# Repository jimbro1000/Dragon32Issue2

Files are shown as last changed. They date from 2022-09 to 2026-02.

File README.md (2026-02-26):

# DRAGON 32 CPU Issue 2 #

This project is a recreation of the SA2120 CPU Mainboard 
for the 1982 Dragon Data **Dragon 32**

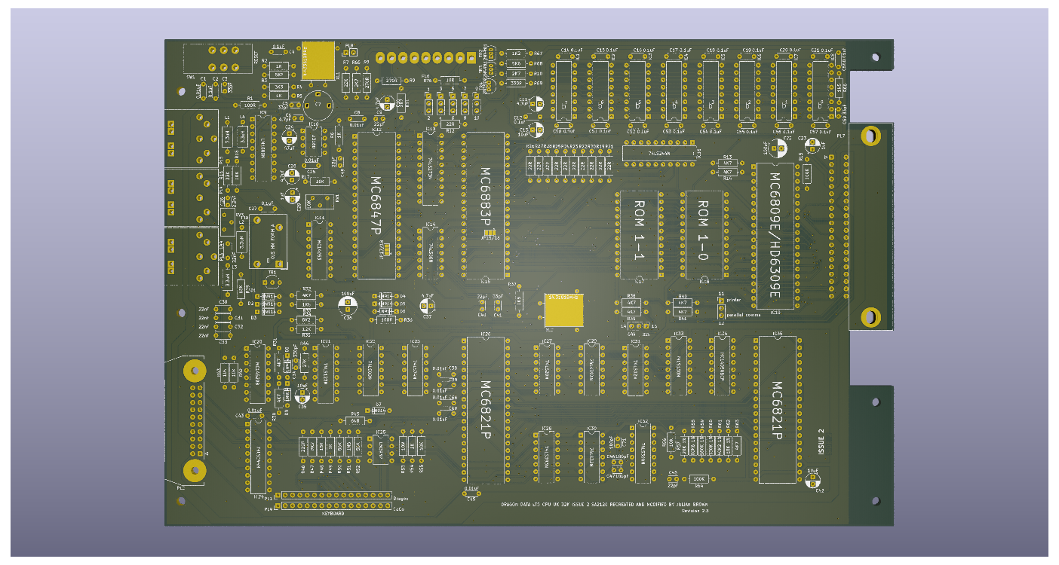
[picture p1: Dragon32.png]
Render of reproduction board


Everything (excluding modifications) is taken from the SA2120
schematics. Component positioning is as close to the original
too. The DRAM positions are as close as possible to the 1982
board but in preference use 4164s instead and set the
memory configuration jumpers appropriately, this avoids 
transplanting a riser board to use the 16x16k configuration.
The 16x16k should still work of course...

The two ROMS will need to be sourced from original boards or an
adapter used to allow the use of modern, available EPROM or EEPROM
components

The variable resistor (RV1) and motor relay (RL1) are adjusted 
for modern, available components. The cartridge port is based
on a modern design but may still be hard to source

## Important - Read This Bit! ##

September 2023: **In the year since I started developing this board the 
availability of the MC6883P/74LS783N SAM chip has gone from "easy to 
find" to almost unobtainable. The only known and proven source is from
DragonPlus Electronics. Please make sure you can find one before starting 
your build**

There is work being done to create a replacement for the SAM chip
but this is yet to become available

The rarer (but ironically easier to buy) 74LS785 should work as
a substitute

## Caveat ##

The scans on the original SA2120 schematics are not always clear
and it has taken a fair amount of careful study to get everything
correct but there is no guarantee at this time that the board 
design is as intended

The values of passive components are taken from observation of
an original production board, in most cases those values do
match the schematics, but not always

Revision 2.3 of this board is in a genuinely usable state but
still with caveats

### Working ###

In the current state (2.3) basic operation is tested working on
CPU, RAM, Keyboard, Joystick and Video.

### Working with caveat ###

Audio appears to be good but not fully tested (given the joysticks
work and the board produces audio there isn't much to go wrong
here)

### Untested ###

Parallel port is untested in either mode beyond verifying signals
to the port are present

## Modifications ##
### Joysticks ###

The two joystick ports provide a second fire button capability
wired to consecutive keyboard rows, as per the Tandy CoCo. 
Unless a two button joystick is used this make no difference to
the operation of the computer. It also requires the use of 6-pin 
DIN sockets, these are pin compatible with the 5-pin originals
so a regular single button joystick can still be used.

The two extra buttons can also be disabled by omitting L3 and L4

### Parallel Port ###

An extra jumper has been introduced to bypass the logic inverter
on the STROBE line. When bypassed the parallel port should 
operate as a communication port for DRIVEWIRE. In effect this
enables the printer port to behave as a TTL serial connection. 
Speed is limited by software and raw clock speed.

### Memory Addressing ###

The board is configurable between 32k and 64k ram addressing
using jumper 13/14. Position 13 is for original 32k ram
configuration, position 14 is for an upgraded 64k ram. Note
that this then requires removal of some additional passive 
components and assumes that suitable 64k x 1 ram chips are 
fitted in IC1 to IC8.

Jumper 9/10 has been added for consistency with some of the
other early designs and for compatibility with the 64k
upgrade. It is important to avoid populating C50-57 when
using this option, along with C12, C58, C59 and R66.

See [World of Dragon: Dragon 32 - 64k Upgrade]
(http://archive.worldofdragon.org/index.php?title=Dragon_32_-_64K_Upgrade)

## Video ##

The Rev 2.1 board adds two (hidden) solder jumpers for adapting
the board to NTSC output. By default these have a bridge putting
the board in PAL mode so unless you want NTSC output there is
nothing to be done.

To change the configuration the bridge on both jumpers needs to be
cut and the option pads bridged with solder. This bypasses the
additional logic for video sync. The jumpers are JP15/16 and 
JP17/18, these are positioned below IC15 and IC12 respectively. 
The default position is marked.

To complete the change an NTSC adapter board needs to be fitted.
This piggybacks the 6847 position and adds in a suitable NTSC
video modulator. The output of the NTSC board goes to PL8, next
to the PAL colour crystal XL1.

In this configuration there is no need to fit a number of components:

* IC9
* IC10
* IC11
* IC14
* IC21
* IC22
* IC26
* IC27
* IC29
* IC30
* IC32
* C2
* C3
* C5
* C6
* C7
* C24
* C25
* C28
* C46
* C47
* C71
* R2
* R3
* R4
* R17
* R18
* R33
* R34
* R35
* R44
* XL1

## Substitutions ##

Many of the original components are simply unobtainable or
just very hard (and expensive) to locate. The transistors
will need modern substitutes as the BC141, BC212 and 2N2369
are all obsolete but thankfully these are fairly run-of-the-mill
transistors and shouldn't cause any particular issues

The video op-amp SFC2318D at position IC10 is especially
hard to find and this one component can easily double the
price of populating the board if an original is used...
I've identified a Harris HA-5111 as a likely candidate, it
is an audio op-amp rated for upto 40MHz so plenty of 
bandwitdh for a simple PAL/NTSC video signal. There are of 
course lots of other single channel op-amps out there in a 
dip-8 format but they tend to be expensive (as in *really*
expensive) possibly cheaper than a real 2318D but not by
much, some are stupidly expensive (nearly 100x that
2318D). The HA-5111 should be about £0.90

The CPU, PIAs and VDG are all fairly easy to obtain online
and possibly even new (MC6821s are still made and there
are lots of compatible alternatives). A and B rated components
should all be usable but make sure the processor is an "09e".
The Hitachi HD6309 is usable but may cause crashes in some
software due to lazy coding

The 4000 series logic chips are particularly tricky - some
have modern equivalents. The MC14053 and MC14050 can be
replaced with modern CD4000 series chips. The MC14529
was replaced with a CD4000 series logic chip but even that
is now obsolete with no valid replacement

The LM1889 is another hard to find chip but still reasonably
cheap online when found

The SAM and the two ROMs are genuinely unavailable except 
from donor boards but the ROMs can be replaced with 27C64
eproms fitted with a suitable conversion shim board.

### The Future ###

As these parts become harder to find it is inevitable that
replacements and redesigns will be needed. Abandoning the
original composite video output circuits and moving to a
(more) modern RGB or VGA output instead removes a big
chunk of the more troublesome hardware, notably the LM1889
and SFC2318 along with a number of other common logic chips.
If a composite output is still required an ADR724J can be
used to generate the necessary signal, all in one chip

A cheat replacement for the 6847 exists, using a raspberry
pi pico but this could easily be reduced even further an
FPGA (assuming such chips are readily available again)

The ROMs can be replaced with a single EPROM/EEPROM, even
opening up the option of switchable ROM images given the
size of a modern EPROM's addressable memory. I have a
mini conversion board that fits into a single socket with
a jumper to the E pin of the second socket. (see 
https://github.com/jimbro1000/Dragon32RomFix)

The one thing that isn't so quickly removed from the
equation is that MC14529 - a dual 4-channel data
selector. Onsemi and Harris used to made the CD4529
that replaced the original MC14529 and it is only fairly 
recently that the chip became obsolete so there is
stock out there but the chip is somewhat specialised and
as such really isnt easily substituted even with a modern
SMD package.

The most likely candidate here is to use a GAL chip to 
simulate the switching behaviour of the MC14529 combined
with discrete analogue switches (such as 74LVC1G3157). This
will necessitate a new board design or a plugin board to
match the pinout of the 4529 chip

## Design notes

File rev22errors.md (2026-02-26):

* jumper 11/12 incorrectly wired to separate direct and inverted signals to STROBE *

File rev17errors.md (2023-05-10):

# Errors found on Rev 1.7 board #

* C7 footprint incorrect - through-hole pads too small for component
* RV3 footprint clashing with PL4 and PL5 - moved to provide additional clearance
* Chrome output from IC9 corrected
* Pins 2 and 3 of IC 10 reversed
* C24 low at 4.7uF, increased to 47uF
* R34 high at 8K8, reduced to 8K2ohms
* R33 low at 1K2, increased to 1K8ohms

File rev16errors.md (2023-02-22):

__Due to a rebase merge conflict earlier corrections have been lost__

* +5V and -5V connections to board are reversed

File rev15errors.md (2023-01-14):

* missing lumcontrol trace added
* correct carry trace between block A and B of IC32
* correct +v to IC25
* correct PIA2/IC35 output to DAC ladder
* revise values for R33, R34 and R35

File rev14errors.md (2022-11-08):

* RL1 footprint reversed
* PL7 mounting holes redesigned to suit original and modern connectors
* PL6 +/-5v power lines reversed

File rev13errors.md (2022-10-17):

* footprint PL7 - updated
* C10 incorrectly wired in schematic - changed to polarized and rewired, only affects 16k layout
* C11 - changed to polarized and rewired
* C13 - changed to polarized and rewired
* C24 - changed to polarized and rewired
* C28 - changed to polarized and rewired
* C37 - changed to polarized and rewired
* C43 - moved to more efficient position
* footprint RL1 - updated
* footprint RV1 - updated
* IC35 - IC20 restored missing connection CB2 <-> STy
* Fix mixup of Q and E on 6883 (IC15)
* R4 pad 2 routed to -5V instead of GND
* IC25 - IC26 restored missing connection to PA7
* IC10 -V connected to -5V instead of GND

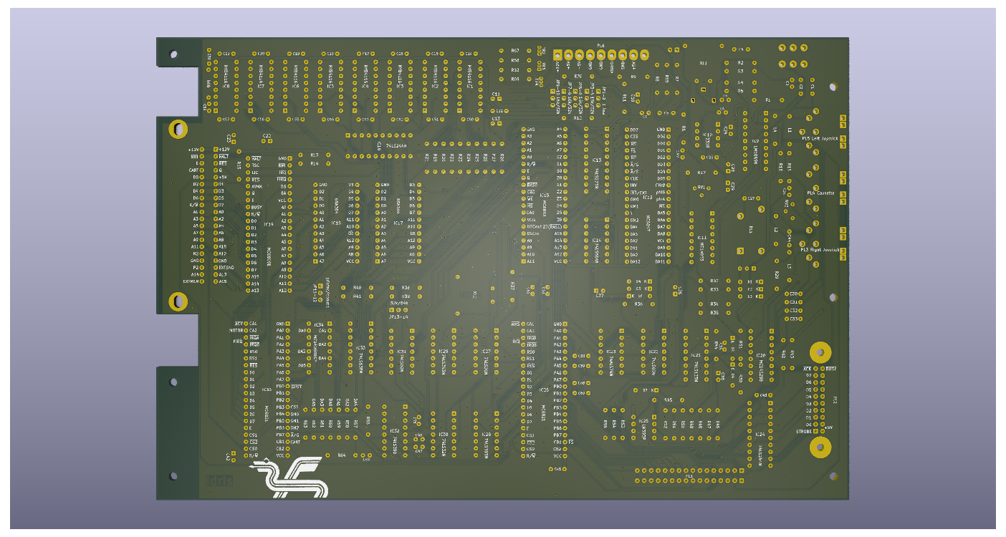
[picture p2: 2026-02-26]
Dragon32c.png

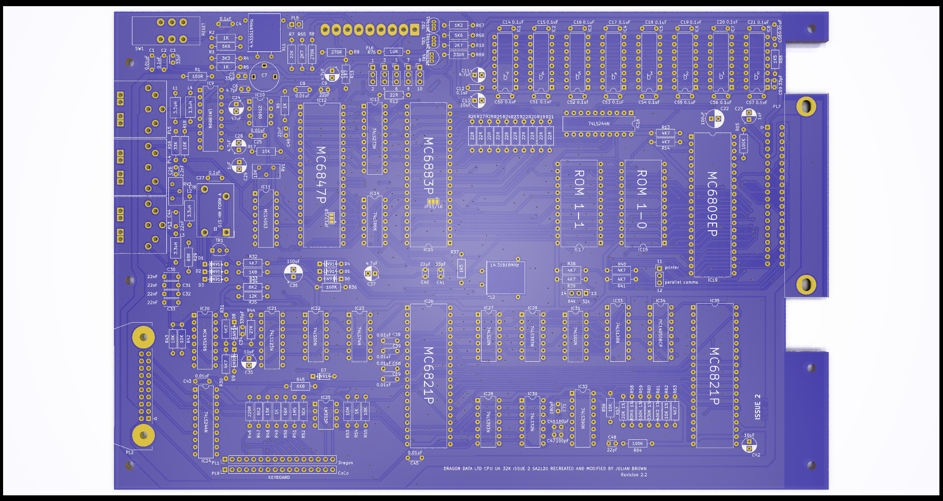
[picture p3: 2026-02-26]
Dragon32b.png

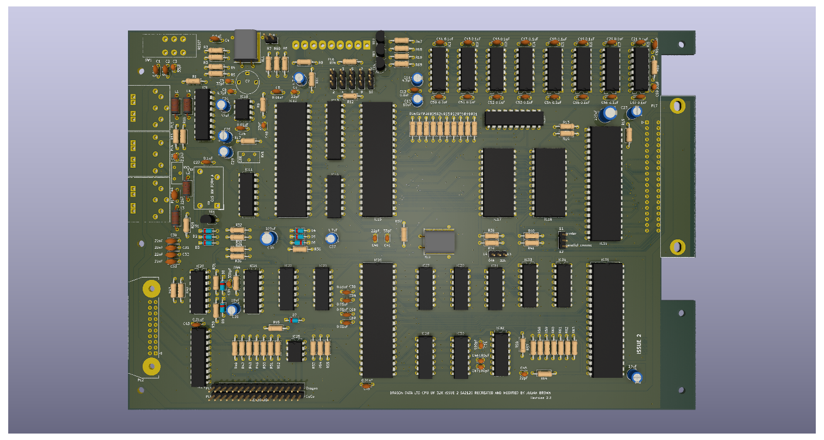
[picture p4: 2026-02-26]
Dragon32a.png

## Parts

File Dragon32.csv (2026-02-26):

Reference | Value | Datasheet | Footprint | Qty | DNP | DigiKey | Mouser
C1,C8,C25,C38,C39,C43,C45,C58,C68,C69 | 0.01uF | https://www.vishay.com/docs/45171/kseries.pdf | Capacitor_THT:C_Disc_D4.3mm_W1.9mm_P5.00mm | 10 |  | BC2662CT-ND
C2,C4,C12,C14,C15,C16,C17,C18,C19,C20,C21,C27,C50,C51,C52,C53,C54,C55,C56,C57 | 0.1uF | https://www.vishay.com/docs/45171/kseries.pdf | Capacitor_THT:C_Disc_D4.3mm_W1.9mm_P5.00mm | 20 |  | BC1101CT-ND
C3,C5,C41,C59 | 33pF | https://www.vishay.com/docs/45171/kseries.pdf | Capacitor_THT:C_Disc_D3.0mm_W2.0mm_P2.50mm | 4 |  | BC1007CT-ND
C6 | 4.7pF |  | Capacitor_THT:C_Disc_D3.0mm_W2.0mm_P2.50mm | 1 |  | 445-180473-1-ND
C7 | 2-22pF | https://connect.kemet.com:7667/gateway/IntelliData-ComponentDocumentation/1.0/download/datasheet/C315C220K2G5TA7301 | Dragon:Trimmer-7.5mm | 1 |  | 4363-PPXE27000-ND
C9,C40,C48,C49 | 22pF | https://connect.kemet.com:7667/gateway/IntelliData-ComponentDocumentation/1.0/download/datasheet/C315C220K2G5TA7301 | Capacitor_THT:C_Disc_D3.0mm_W2.0mm_P2.50mm | 4 |  | 399-13930-1-ND
C10,C11,C28,C37 | 4.7uF | https://datasheets.kyocera-avx.com/tap.pdf | Capacitor_THT:CP_Radial_D5.0mm_P2.50mm | 4 |  | 478-8984-1-ND
C13,C35,C42 | 10uF | https://www.we-online.com/katalog/datasheet/860010372001.pdf | Capacitor_THT:CP_Radial_D5.0mm_P2.50mm | 3 |  | 732-8593-1-ND
C22,C36 | 100uF | https://www.we-online.com/katalog/datasheet/860010372006.pdf | Capacitor_THT:CP_Radial_D6.3mm_P2.50mm | 2 |  | 732-8598-1-ND
C23,C29 | 1uF | https://www.we-online.com/katalog/datasheet/860020772005.pdf | Capacitor_THT:CP_Radial_D5.0mm_P2.50mm | 2 |  | 732-8966-1-ND
C24 | 47uF | https://datasheets.kyocera-avx.com/tap.pdf | Capacitor_THT:CP_Radial_D5.0mm_P2.50mm | 1 |  | 478-8984-1-ND
C26 | 2.2nF | https://www.vishay.com/docs/45171/kseries.pdf | Capacitor_THT:C_Disc_D3.0mm_W2.0mm_P2.50mm | 1 |  | BC1074CT-ND
C30,C31,C32,C33,C44 | 22nF | https://www.vishay.com/docs/45171/kseries.pdf | Capacitor_THT:C_Disc_D5.0mm_W2.5mm_P5.00mm | 5 |  | BC2677CT-ND
C34 | 330pF | https://www.vishay.com/docs/45171/kseries.pdf | Capacitor_THT:C_Disc_D3.0mm_W2.0mm_P2.50mm | 1 |  | BC1045CT-ND
C46,C71 | 180pF | https://www.vishay.com/docs/45171/kseries.pdf | Capacitor_THT:C_Disc_D3.0mm_W2.0mm_P2.50mm | 2 |  | BC1016CT-ND
C47 | 100pF | https://connect.kemet.com:7667/gateway/IntelliData-ComponentDocumentation/1.0/download/datasheet/C316C101J5G5TA7303 | Capacitor_THT:C_Disc_D3.0mm_W2.0mm_P2.50mm | 1 |  | 399-C316C101J5G5TA7303CT-ND
D1,D2,D3,D4,D5,D6,D7,D8,D9 | 1N914 | http://www.vishay.com/docs/85622/1n914.pdf | Diode_THT:D_DO-35_SOD27_P7.62mm_Horizontal | 9 |  | 1N914FS-ND
IC1,IC2,IC3,IC4,IC5,IC6,IC7,IC8 | HYB4116 | https://4donline.ihs.com/images/VipMasterIC/IC/INFN/INFNS18263/INFNS18263-1.pdf | Package_DIP:DIP-16_W7.62mm | 8 |  |  | 517-4816-3000-CP
IC9 | LM1889N | https://www.alldatasheet.com/datasheet-pdf/pdf/8687/NSC/LM1889N.html | Package_DIP:DIP-18_W7.62mm | 1 |  |  | 517-4818-3000-CP
IC10 | 2318 | https://ww1.microchip.com/downloads/en/DeviceDoc/20001811F.pdf | Package_DIP:DIP-8_W7.62mm | 1 |  | MCP6281-E/P-ND
IC11 | MC14053 | https://rocelec.widen.net/view/pdf/kdbfj5guvk/MOTOS09506-1.pdf?t.download=true&u=5oefqw | Package_DIP:DIP-16_W7.62mm | 1 |  | 296-2059-ND
IC12 | MC6847 |  | Package_DIP:DIP-40_W15.24mm | 1 |  |  | 517-4840-6000-CP
IC13 | 74LS273N | http://www.ti.com/lit/gpn/sn74LS273 | Package_DIP:DIP-20_W7.62mm | 1 |  | 296-1657-5-ND
IC14 | 74LS86AN | https://media.digikey.com/pdf/Data%20Sheets/Fairchild%20PDFs/DM74LS86.pdf | Package_DIP:DIP-14_W7.62mm | 1 |  | 296-1669-5-ND
IC15 | MC6883 | http://www.colorcomputerarchive.com/coco/Documents/Datasheets/MC6883 Synchronous Address Multiplexer (Motorola).pdf | Package_DIP:DIP-40_W15.24mm | 1 |  |  | 517-4840-6000-CP
IC16,IC24 | 74LS244N | http://www.ti.com/lit/ds/symlink/sn74ls244.pdf | Package_DIP:DIP-20_W7.62mm | 2 |  | 296-1653-5-ND
IC17,IC18 | 68A364 |  | Package_DIP:DIP-24_W15.24mm | 2 |  |  | 517-4824-6000-CP
IC19 | MC6809E | http://pdf.datasheetcatalog.com/datasheet/motorola/MC68B09S.pdf | Package_DIP:DIP-40_W15.24mm | 1 |  |  | 517-4840-6000-CP
IC20 | MC14529B |  | Package_DIP:DIP-16_W7.62mm | 1 |  | CD4529BCN-ND
IC21 | 74LS123N | http://www.ti.com/lit/gpn/sn74LS123 | Package_DIP:DIP-16_W7.62mm | 1 |  | 296-1636-5-ND
IC22 | 74LS00N | http://www.ti.com/lit/gpn/sn74ls00 | Package_DIP:DIP-14_W7.62mm | 1 |  | 296-1626-ND
IC23 | 74ALS74N | https://www.ti.com/lit/ds/symlink/sn74als74a.pdf | Package_DIP:DIP-14_W7.62mm | 1 |  | 296-1506-5-ND
IC25 | LM393P | http://www.ti.com/lit/ds/symlink/lm393.pdf | Package_DIP:DIP-8_W7.62mm | 1 |  | 296-1398-5-ND
IC26,IC35 | MC6821 |  | Package_DIP:DIP-40_W15.24mm | 2 |  |  | 517-4840-6000-CP
IC27 | 74LS20N | http://www.ti.com/lit/gpn/sn74LS20 | Package_DIP:DIP-14_W7.62mm | 1 |  | 296-3670-5-ND
IC28,IC29 | 74LS393N | https://www.ti.com/general/docs/suppproductinfo.tsp?distId=10 | Package_DIP:DIP-14_W7.62mm | 2 |  | 296-1665-5-ND
IC30 | 74LS32N | http://www.ti.com/lit/gpn/sn74LS32 | Package_DIP:DIP-14_W7.62mm | 1 |  | 296-1658-5-ND
IC31 | 74LS02N | http://www.ti.com/lit/gpn/sn74ls02 | Package_DIP:DIP-14_W7.62mm | 1 |  | 296-1627-5-ND
IC32 | 74LS390 | http://www.ti.com/lit/gpn/sn74LS390 | Package_DIP:DIP-16_W7.62mm | 1 |  | 296-26516-5-ND
IC33 | 74LS138N | http://www.ti.com/lit/gpn/sn74LS138 | Package_DIP:DIP-16_W7.62mm | 1 |  | 296-1639-5-ND
IC34 | MC14050BCP | https://media.digikey.com/pdf/Data%20Sheets/ON%20Semiconductor%20PDFs/MC14049B,50B_Rev7.pdf | Package_DIP:DIP-16_W7.62mm | 1 |  | 296-2056-ND
JP1-2 | 1 low | ~ | Connector_PinHeader_2.54mm:PinHeader_1x03_P2.54mm_Vertical | 1 |  |  | 538-22-28-5033
JP3-4,JP5-6,JP7-8,JP9-10 | 16k/32k | ~ | Connector_PinHeader_2.54mm:PinHeader_1x03_P2.54mm_Vertical | 4 |  |  | 538-22-28-5033
JP11-12 | printer/comms | ~ | Connector_PinHeader_2.54mm:PinHeader_1x03_P2.54mm_Vertical | 1 |  |  | 538-22-28-5033
JP13-14 | 32k/64k | ~ | Connector_PinHeader_2.54mm:PinHeader_1x03_P2.54mm_Vertical | 1 |  |  | 538-22-28-5033
L1,L2,L3,L4 | 3.3uH | ~ | Inductor_THT:L_Axial_L7.0mm_D3.3mm_P10.16mm_Horizontal_Fastron_MICC | 4 |  | 495-5561-1-ND
PL1 | Dragon Keyboard | ~ | Connector_PinHeader_2.54mm:PinHeader_1x16_P2.54mm_Vertical | 1 |  | 952-2521-ND
PL2 | Printer | https://media.digikey.com/pdf/Data%20Sheets/CW%20Industries%20PDFs/CWN-300%20Ordering.pdf | Connector_IDC:IDC-Header_2x10-1MP_P2.54mm_Latch_Horizontal | 1 |  | CHR20G-ND
PL3 | DIN-6 J/S R | https://www.dem-uk.com/deltron-components/Data/Product_Downloads/deltron-671-0501-5-way-din-socket-data.pdf | Dragon:DIN-6_DELTRON_671-0601_Horizontal | 1 |  | CP-7060-ND
PL4 | DIN-5 (180) Cassette | https://www.dem-uk.com/deltron-components/Data/Product_Downloads/deltron-671-0501-5-way-din-socket-data.pdf | Dragon:DIN-5_DELTRON_671-0501_45deg_Horizontal | 1 |  | CP-7050-ND
PL5 | DIN-6 J/S L | https://www.dem-uk.com/deltron-components/Data/Product_Downloads/deltron-671-0501-5-way-din-socket-data.pdf | Dragon:DIN-6_DELTRON_671-0601_Horizontal | 1 |  | CP-7060-ND
PL6 | Power Board Interconnect | https://app.adam-tech.com/products/download/data_sheet/241222/lhd-xx-ts-data-sheet.pdf | Connector_Molex:Molex_KK-396_A-41791-0009_1x09_P3.96mm_Vertical | 1 |  | 2057-LHD-09-TS-ND
PL7 | EDAC 392-040-558-201 | https://files.edac.net/edac/content/342/342-040-558-212%20-%20EDAC%20Card%20Edge%20Connector.PDF | Dragon:Edge_2x20_P2.54mm_OvalMP | 1 |  | 151-342-040-558-201-ND | 587-342-040-558-201
PL8 | video | ~ | Connector_PinHeader_2.54mm:PinHeader_1x02_P2.54mm_Vertical | 1 |  |  | 538-22-28-4024
PL9 | CoCo Keyboard | ~ | Connector_PinHeader_2.54mm:PinHeader_1x16_P2.54mm_Vertical | 1 |  |  | 538-22-28-8161
R1 | 100R | ~ | Resistor_THT:R_Axial_DIN0207_L6.3mm_D2.5mm_P10.16mm_Horizontal | 1 |  | CF14JT100RCT-ND
R2,R5,R6,R49,R54 | 1K | ~ | Resistor_THT:R_Axial_DIN0207_L6.3mm_D2.5mm_P10.16mm_Horizontal | 5 |  | CF14JT1K00CT-ND
R3,R68 | 5K6 | ~ | Resistor_THT:R_Axial_DIN0207_L6.3mm_D2.5mm_P10.16mm_Horizontal | 2 |  | CF14JT5K60CT-ND
R4 | 3K3 | ~ | Resistor_THT:R_Axial_DIN0207_L6.3mm_D2.5mm_P10.16mm_Horizontal | 1 |  | CF14JT3K30CT-ND
R7 | 22K | ~ | Resistor_THT:R_Axial_DIN0207_L6.3mm_D2.5mm_P10.16mm_Horizontal | 1 |  | CF14JT22K0CT-ND
R8,R9 | 270R | ~ | Resistor_THT:R_Axial_DIN0207_L6.3mm_D2.5mm_P10.16mm_Horizontal | 2 |  | CF14JT270RCT-ND
R10,R11,R65 | 2K7 | ~ | Resistor_THT:R_Axial_DIN0207_L6.3mm_D2.5mm_P10.16mm_Horizontal | 3 |  | CF14JT2K70CT-ND
R12,R19,R20,R21,R22,R23,R24,R25,R26,R27,R28 | 22R | ~ | Resistor_THT:R_Axial_DIN0207_L6.3mm_D2.5mm_P10.16mm_Horizontal | 11 |  | CF14JT22R0CT-ND
R13,R14,R30,R31,R32,R38,R39,R40,R41,R63 | 4K7 | ~ | Resistor_THT:R_Axial_DIN0207_L6.3mm_D2.5mm_P10.16mm_Horizontal | 10 |  | CF14JT4K70CT-ND
R15,R36,R64 | 100K | ~ | Resistor_THT:R_Axial_DIN0207_L6.3mm_D2.5mm_P10.16mm_Horizontal | 3 |  | CF14JT100KCT-ND
R16 | 33K | ~ | Resistor_THT:R_Axial_DIN0207_L6.3mm_D2.5mm_P10.16mm_Horizontal | 1 |  | CF14JT33K0CT-ND
R17,R18,R42,R43,R55,R56 | 10K | ~ | Resistor_THT:R_Axial_DIN0207_L6.3mm_D2.5mm_P10.16mm_Horizontal | 6 |  | CF14JT10K0CT-ND
R29 | 68K | ~ | Resistor_THT:R_Axial_DIN0207_L6.3mm_D2.5mm_P10.16mm_Horizontal | 1 |  | CF14JT68K0CT-ND
R33 | 1K8 | ~ | Resistor_THT:R_Axial_DIN0207_L6.3mm_D2.5mm_P10.16mm_Horizontal | 1 |  | CF14JT3K30CT-ND
R34,R47 | 8K2 | ~ | Resistor_THT:R_Axial_DIN0207_L6.3mm_D2.5mm_P10.16mm_Horizontal | 2 |  | CF14JT8K20CT-ND
R35 | 12K | ~ | Resistor_THT:R_Axial_DIN0207_L6.3mm_D2.5mm_P10.16mm_Horizontal | 1 |  | CF14JT15K0CT-ND
R37,R66 | 1K5 | ~ | Resistor_THT:R_Axial_DIN0207_L6.3mm_D2.5mm_P10.16mm_Horizontal | 2 |  | CF14JT1K50CT-ND
R44 | 27K | ~ | Resistor_THT:R_Axial_DIN0207_L6.3mm_D2.5mm_P10.16mm_Horizontal | 1 |  | CF14JT27K0CT-ND
R45 | 6K8 | ~ | Resistor_THT:R_Axial_DIN0207_L6.3mm_D2.5mm_P10.16mm_Horizontal | 1 |  | CF14JT6K80CT-ND
R46 | 220R | ~ | Resistor_THT:R_Axial_DIN0207_L6.3mm_D2.5mm_P10.16mm_Horizontal | 1 |  | CF14JT220RCT-ND
R48 | 15K | ~ | Resistor_THT:R_Axial_DIN0207_L6.3mm_D2.5mm_P10.16mm_Horizontal | 1 |  | CF14JT15K0CT-ND
R50,R52 | 56K | ~ | Resistor_THT:R_Axial_DIN0207_L6.3mm_D2.5mm_P10.16mm_Horizontal | 2 |  | CF14JT56K0CT-ND
R51 | 1M5 | ~ | Resistor_THT:R_Axial_DIN0207_L6.3mm_D2.5mm_P10.16mm_Horizontal | 1 |  | CF14JT1M50CT-ND
R53 | 10M | ~ | Resistor_THT:R_Axial_DIN0207_L6.3mm_D2.5mm_P10.16mm_Horizontal | 1 |  | CF14JT10M0CT-ND
R57 | 20K 1% | ~ | Resistor_THT:R_Axial_DIN0207_L6.3mm_D2.5mm_P10.16mm_Horizontal | 1 |  | RNF14FTD20K0CT-ND
R58 | 80K6 1% | ~ | Resistor_THT:R_Axial_DIN0207_L6.3mm_D2.5mm_P10.16mm_Horizontal | 1 |  | RNF14FTD80K6CT-ND
R59 | 160K 1% | ~ | Resistor_THT:R_Axial_DIN0207_L6.3mm_D2.5mm_P10.16mm_Horizontal | 1 |  | S160CACT-ND
R60 | 330K 1% | ~ | Resistor_THT:R_Axial_DIN0207_L6.3mm_D2.5mm_P10.16mm_Horizontal | 1 |  | S330KCACT-ND
R61 | 40K2 1% | ~ | Resistor_THT:R_Axial_DIN0207_L6.3mm_D2.5mm_P10.16mm_Horizontal | 1 |  | RNF14FTD41K2CT-ND
R62 | 10K 1% | ~ | Resistor_THT:R_Axial_DIN0207_L6.3mm_D2.5mm_P10.16mm_Horizontal | 1 |  | RNF14FTD10K0CT-ND
R67 | 1K2 | ~ | Resistor_THT:R_Axial_DIN0207_L6.3mm_D2.5mm_P10.16mm_Horizontal | 1 |  | CF14JT1K20CT-ND
R69 | 330R | ~ | Resistor_THT:R_Axial_DIN0207_L6.3mm_D2.5mm_P10.16mm_Horizontal | 1 |  | CF14JT330RCT-ND
R76 | 10R | ~ | Resistor_THT:R_Axial_DIN0207_L6.3mm_D2.5mm_P10.16mm_Horizontal | 1 |  | CF14JT10R0CT-ND
RL1 | OJS HM FORM A | https://www.te.com/commerce/DocumentDelivery/DDEController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 | Dragon:OJS HM 10A Relay | 1 |  | 41-OJS-SH-105HMF,00000-ND
RV1 | 10K | ~ | Potentiometer_THT:Potentiometer_Bourns_3386X_Horizontal | 1 |  | 3386C-103LF-ND
RV3 | 470R | ~ | Potentiometer_THT:Potentiometer_Bourns_3386X_Horizontal | 1 |  | 3386H-103LF-ND
SW1 | RESET | https://www.ckswitches.com/media/1402/fpush.pdf | Dragon:Button_AlpsAlpine_SPUN190900 | 1 |  | 401-1225-ND
TR1 | BC141 | https://alltransistors.com/adv/pdfview.php?doc=bc140_bc141_cnv_2.pdf&dire=_philips | Package_TO_SOT_THT:TO-92_Inline_Wide | 1 |  | SS8050DTACT-ND
TR2,TR3 | 2N4401 | http://www.farnell.com/datasheets/296634.pdf | Package_TO_SOT_THT:TO-92_Inline | 2 |  | 2N4401D26ZCT-ND
TR4 | 2N3906 | https://www.onsemi.com/pub/Collateral/2N3906-D.PDF | Package_TO_SOT_THT:TO-92_Inline | 1 |  | 2N3906D26ZCT-ND
XL1 | 4.433619MHz | https://www.we-online.com/catalog/datasheet/830003099B.pdf | Crystal:Crystal_HC49-U_Horizontal | 1 |  | 1923-830003099B-ND
XL2 | 14.31818MHz | https://www.ctscorp.com/wp-content/uploads/MP.pdf | Crystal:Crystal_HC49-U_Horizontal | 1 |  | CTX088-ND

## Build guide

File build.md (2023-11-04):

# Dragon 32 Rev 2 Build Instructions #

## Introduction ##

This is a rough guide on how to assemble the 
Dragon 32 Rev 2 reproduction board. It assumes 
you have collected together all the parts you 
will need using the bill of materials in the 
project repository.

## Preparation ##

Clean the mainboard to remove contaminants, soapy
water first, dry and then a wipe down with 
isopropy alcohol.

Make sure you have a good supply of solder, a
temperature controlled soldering iron. If you
are using lead based solder set the temperature
to between 360C and 370C. The board can tolerate
higher for lead-free solder.

A ready supply of solder flux can be really
helpful if you find yourself having to remove a
component from the board.

You will need short tipped, angled wire cutters
for trimming the component leads after soldering.
Don't cut the leads right down to the board or deep
into the solder.

It is also a good idea to have a multimeter on hand
to check component values and test for any shorts
after soldering.

The project repository on GitHub includes an
interactive Bill Of Materials that allows you to
cross-reference components against position on
the board (and mark off all the parts that you've
fitted). To use this download the ibom.html file
to your computer and open it from the local file
system (this should open up a web browser).

If you can't or don't want to use the iBOM it is
a good idea to print off the Dragon32__Assembly 
PDF on to large form paper and mark the positions 
off from there as they are fitted to help avoid
getting lost.

## Build Order ##

Work with the components with the lowest profile
first - resistors, then diodes, then capacitors,
transistors, etc.

Leaving the chip sockets until last helps as they 
tend to get in the way when fitting other items.

### PAL/NTSC configuration ###

If you are setting the board up to use NTSC you
need to start by modifying JP15/16 and JP17/18.
By default these are pre-bridged for PAL use.
You need to cut the trace joining pads 1 and 2
on both jumpers. Pad 1 is marked with a triangle.

Once the trace is cut, use a blob of solder to
join pads 2 and 3.

To use NTSC you need to provide an adapter to the
VDG that includes an MC1372 NTSC modulator chip.
This replaces most of the discrete logic on the
board.

The output of the adapter board is wired to PL8.
Ground on the left, composite NTSC video on the
right.

The rest of this build assumes you are assembling
for a PAL machine.

### Resistors ###

Fit resistors first making sure the solder is
forming on both sides of the board, not just
the bottom.

Regardless of board configuration all of the
resistors should be fitted.

Save the two potentiometer resistors RV1 and RV2
for later.

### Diodes ###

Fit all 9 diodes in much the same way as the
resistors but making sure the polarity marking
matches the board.

### Inductors ###

If you want to have the option of two button
joysticks (non-standard but used in some
CoCo games) then you'll need to fit all 4
inductors (L1-L4).

If you only want single button joysticks you
only need to fit L1 and L2.

Soldering is the same as for resistors.

### Capacitors ###

If you are using 4164 DRAM chips you need to
miss some components out. C12 and C50-C57
must not be fitted - failing to do this will
result in corrupted memory read and write.

Other than this fit all capacitors making 
sure that the tantalum and electrolytic
capacitors are fitted the right way around.

Tantalum capacitors have a + symbol next to
the positive side. Electrolytic capacitors
have an arrow pointing to the negative side.

The board is marked to show a + next to the
positive side and a filled semicircle on the
negative side.

It is worth saving two of the long legs
after trimming the legs back. You can use
these for securing the crystals.

Save the trim pot capacitor C7 for later.

### Transistors ###

TR1 is an NPN transistor driving the coil of
the cassette remote relay. It uses a wide
TO-92 footprint.

TR2 and TR3 are NPN transistors in the
video amplification circuit.

TR4 is a PNP transistor acting as the
final amplifier in the video circuit.

TR2-TR4 all use a narrow TO-92 footprint.

It may require some leg bending to form
your transistors to the right spacing. 
This is best done with a pair of tweezers
to reshape the legs as needed. Trying to
do this by hand is likely to result in
snapped legs.

Make sure the transistors are fitted the
right way around according to the outline
printed on the board.

### Jumper Posts ###

The board has 7 configuration jumpers. All
of these are 3 posts. Soldering them can
be tricky when trying to get them aligned
vertically. A simple approach is to only
tack a single pin and then adjust the angle
until happy.

If you know the configuration you are going
for and do not wish to change it later you
can safely use a piece of wire to bridge 
the desired contacts.

This is fine for jumpers JP1/2 through to 
JP9/10 but it is recommended to fit the 
three post headers for JP11/12 and JP13/14.

### Connectors ###

The keyboard connector can be vertical or
a horizontal as desired. Original boards
used a vertical orientation but later boards
and the D64 moved to horizontal to avoid 
clashing with the keyboard itself. I
recommend using the horizontal option as
it leaves more space for connectors.

The joystick and cassette port connectors
have an overlapping design, if you want
to get them nicely lined up start with the
5-pin cassette socket and tack it in
place on a single pin.

You can then do the same with the two
joystick ports (6-pin or 270deg 5-pin)
and align them to the edge of the board.
This can be a tricky task so don't rush
it.

The power board connector needs to be 
fitted with the vertical guide towards
the bottom of the board (assuming you
don't have a plain pin header).

The cartridge port connector can be very
entertaining to fit. The pins like to
bend in transit so you'll likely find
yours do not line up on the first attempt.
It is very easy to bend the pins on the
cheaper connectors resulting in the pin
not fitting properly. Double check that
all pins have fitted through the mounting
holes on the board before soldering.

### Variable Components ###

C7 should fit easily but some varistors
have legs that can split into multiple
layers. Make sure that all of the leg
makes it through the mounting holes.

RV1 needs to be fitted at an angle so
that the adjustment side is facing more
upwards. The long, flexible legs of the
part make this relatively easy to 
achieve. If you fit it flush and then
trim the legs before realising you can't
easily adjust it, you will need to
obtain a replacement or work with it
as-is.

RV2 has a top adjustment and can be 
fitted flush to the board but the legs
of the component need to be checked.
Some versions of the part have the legs
in-line while the board expects the
middle leg to be offset. As with RV1
the legs are flexible and be easily
formed to the right configuration.

The orientation of RV1 and RV2 is not
critical, it just changes which way
you turn the adjustment.

### Crystals ###

Assuming you have the larger housed
crystals you will need to bend the legs
so the crystal lies flush with the board.
This is not essential but it is 
recommended. Two additional solder points
are provided for each crystal to allow a
wire to be formed over the body and 
prevent the crystal being moved. A
convenient source for the wire to do this
is the long legged capacitors you 
hopefully saved earlier.

### Sockets ###

When fitting the sockets make sure the
orientation is correct and the notch of
the socket matches the outline on the
board.

Most of the chips are aligned with the 
notch to the top of the board but RAM, ROM
and SAM chips have the notch towards
the bottom of the board.

As with the header pins it can be a 
little tricky to get the sockets to fit
flush and aligned. Tacking one pin at 
each end of the socket to hold it in
place and then heating one pin while
adjusting the position gives a good
result.

Be very careful to avoid bridging the
pins on the socket while soldering.
It is worth checking with a multimeter
to double check as the pins can 
bridge on the top of the board, hidden
underneath the socket.

If you are using original ROMs for U17 and 
U18 it is worth fitting regular double
wipe leaf sockets. If you are using EPROMS
in adapters you can either fit the adapters
straight to the board (definitely recommended
for square pins) or fit turned pin sockets 
(only for round pins on the adapter).

### Before Fitting Chips ###

As a precaution, before fitting the
chips to the board it is worth making
sure none of the voltage pins of the
power board connector are shorted to
ground (that would be bad).

The power connector has the voltages
as +12v, +5v, -5v, Gnd going from
right to left. You don't need to connect
to the power supply to test, you just
need to check continuity between the
power pins and the different power pins
on the various sockets.

If you fit your configuration jumpers
next to the power connector (JP1/2 to
JP9/10) you can make sure the right
voltages are available on the board
by checking for continuity from the 
respective power pins.

The +5v pin is connected to almost
every single chip on the board as Vcc.
On the 74LS logic chips this is the 
upper right pin. The lower left pin
is connected to ground.

The RAM chips take a little more attention. 
For 4164 chips there are  only two power 
pins, +5v and ground. +5V should be the top 
right pin. Gnd should be the lower left pin.

The LM1889 modulator IC9 needs different
voltages, -5V to pin 5 (5th pin down on
the left side) and +5V to pin 14 (5th pin
down on the right side).

The amplifier at IC25 needs +12V on the top
right pin.

The amplifier at IC10 needs -5V on the lower
left pin and +5V on pin 7 (2nd pin down on
the right).

You should also have +5V on the left pin of
R67. You should have -5V on the left pin of
R69. These are the top and bottom resistors
just to the left of the ram bank.

### Bonus Jumpers ###

JP11/12 is used to disable the inverter
driving the strobe pin of the printer port. 
While this is "on" (11) the strobe pin will not 
work for input. If you want to use the
printer port for bit banging a serial port
you will need to disable the inverter by
setting the jumper to the 12 position.

JP13/14 defines whether the board is working
in "half-good" 4164 mode or full 64k mode.
If you only want your board to work as a D32
then set this to 13, if you want to be able
to access the full 64k memory mode (which
will break your ROM access) then set the
jumper to 14.

In effect JP13/14 is the part of the 
memory upgrade mod that requires bodging
and cutting traces between chips.

### Fitting Chips ###

Make sure you have a grounding strap on your
wrist (or ankle) and it is actually connected
to a proven ground point (radiators are a 
good source). The LM1889 and DRAM chips are
very susceptible to static discharge! Leave
these until last.

Fit all your chips paying very careful attention
to orientation, notches must match with the
board. Fitting chips the wrong way round will 
likely destroy them when the power is switched
on.

### ROM Chips ###

If you have original ROMs you fit these directly
to sockets. EPROMs require an adapter board which
probably has a socket on top so the adapter can
be directly soldered to the board, unless you want 
to keep changing them. If you are going to chop
and change between original and EPROMs I recommend
fitting turned pin sockets and creating a sandwich
of regular leaf pin and turned pin sockets for the
ROMs to fit in. This will avoid damaging your
valuable ROMs and maintain good contact to the 
board.

### First Power Up ###

Before turning the power on for the first time it
is worth removing the LM1889 modulator, it provides
the colour signal but the video will work in 
monochrome without it.

When powering on for the first time always be
prepared to turn the power off in a hurry. If it
doesn't show a picture on your monitor it does not
mean it isn't working, you may need to adjust RV1
to bring the output into an acceptable voltage range

If anything smokes or looks to be getting hot, turn
the power off immediately. You most likely have a 
short (you did check for shorts?) or a polarised
capacitor in backwards.

Assuming nothing goes pop you should be able to
adjust the video output to get a stable picture.
If all goes well, turn the power off and reinsert
the LM1889 modulator.

Try the video again and you should be welcomed by
the regular green screen. You can adjust the 
video timing by turning the head on C7. This is
best done with a plastic screwdriver, not a metal
one. When set correctly you should be able to just
about freeze horizontal dot crawl but won't be able
to remove horizontal artifacts.

### Troubleshooting ###

#### No Colour ####
In most cases this will be a failed LM1889. Test
the clock signal on PIN 17 of the modulator. If you
can see a good 4.3MHz signal you should be seeing 
colour. Check RV1 is set appropriately and that the 
colour signal is arriving at R7 (lower leg, not the
top one) and again at R10 (left leg, not the right).

If the signal is getting that far then you likely have
a bad TR2 (or the wrong component, or a short between
pins on TR2 - easily done).

If the signal is not getting to the test points, check
for continuity.

If you are only getting clear colour on alternating
lines the problem will sit with the amplifier at IC10.
This mixes the signal for alternating lines. The chip
is pretty robust but I've seen failures during testing
that left me scratching my head...

#### Garbage Picture ####
There are many, many ways that this can happen. The 
most common cause is a stuck data line, either due
to bad RAM/ROM or a short between data lines or
address lines.

Test your RAM - either in a known good device or
with a dedicated RAM tester (beware that some testers
can show a failure for good chips due to differences
between TTL and CMOS). The ROMs on the Dragon are
generally robust but the same chip type is a common
source of failure on other computers (cough Commodore).
It is worth checking the legs are making good contact
with no sign of corrosion (blackening).

#### No Response At All ####
If the relay doesn't click on powering up (assuming
you fitted one) and there is no picture at all, the
chances are the CPU is not cycling. Either it hasn't
come out of reset or is being locked up by another
line.

A bad PIA can cause the CPU to run very, very slowly
by generating interrupt requests at high frequency.
Try removing the PIAs and try running without them.

Check the reset line is going high (about 5V) and the
same again for halt, mrdy, extal, xtal, bs and ba pins.
If any of these are low it can stop the CPU operating.

Check the Q and E pins are oscillating at (about) 
0.9MHz, no clock means no CPU. You can also check
the SAM is receiving the full 14MHz clock from the
crystal.

If all is well with those pins, test the address and
data lines with an oscilloscope or logic probe. You
should see activity with the lines moving from high
to low.

If the CPU is doing nothing it may be faulty, either
test the CPU in a known good machine or try a different
CPU.

If the CPU is proven good you can turn your attention
to the SAM, this governs the CPU activity and memory
addressing. I've yet to see one fail but if it does
you have no hope of getting the computer to work until
it is replaced. More likely the SAM is not getting 
the input signals it needs to operate.

Check the clock input and the Q/E output of the SAM.
If the clock is present and correct, check the SAM 
is generating RAM addressing signals on the Z lines 
and RAS/CAS lines.

The SAM also decides what device is being addressed
it does this though a multiplexer at IC33. Check the
operation of this chip carefully. Also make sure you
have a jumper clip on JP13/14 as a missing signal here
will disable the multiplexer!

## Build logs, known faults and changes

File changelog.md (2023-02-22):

# Revision 1.8 #
# Unpublished

* Fix rebase/merge errors from between 1.6 and 1.7
* +5v and -5v fixed (again)
* CL7 footprint design updated 
* RV3 moved for clearance
* Migrate to Kicad 7
* Chome subcarrier of IC9 used instead of chnB

# Revision 1.7 #
# Published 14/01/2023 

* Add missing lumcontrol trace
* Correct carry trace between block A and B of IC32
* Revise position and orientation of IC17 and IC18
* Rework traces for all RAM wiring including ground plane provision
* Use suitable footprint for C7
* Update README with notes on using 4164s instead of 4116s
* Correct +v on IC25 from +5 to +12
* Reverse DAC ladder output from IC35
* Revise resistor values for line pulse padding

# Revision 1.6 #
# Published 08/11/2022

* Fix RL1 footprint
* Redesign PL7 mounting points
* Fix PL6 connections
* Improve trace spacing to reduce crosstalk
* Add secondary video amp bypass circuit
* Reposition RV1 to improve access for adjustment
* Change C7 footprint to accomodate trimmer
* Change TR1 footprint to use wider pitch
* Improve silkscreen text for clarity

# Revision 1.5 #
# Published 15/10/2022

* Fix incorrect wiring on C10
* Fix connection between IC35 and IC20 CB2 <-> STy
* Fix connection between IC25 and IC26 PA7
* Fix GND bias on IC10 to use -5V instead of 0V
* Fix R4 to use -5V instead of 0V
* Fix schema error on IC15, reversed Q and E
* Updated C11, C13, C24, C28, C37 to use polarized footprint
* Updated footprint for cartridge port PL7
* Moved board mounting holes to ease fitting
* Moved C43, C58, C59, R66
* Review passive component values vs original board
* Added more detail to front and back silkscreen
* Changed RL1 to use footprint for available part
* Changed RV1 to use common bourns footprint
* Aligned DIN sockets to edge of board (slight overhang)
* Identify parts with DigiKey part numbers for verification
* Trimmed bottom of board

# Revision 1.4 #
# Published 30/09/2022

* Revise positions of IC1-8 and IC16 for compatibility with original riser board

Note: this is not a tested working board. For evaluation only

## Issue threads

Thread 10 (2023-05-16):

Video circuit errors

jimbro1000, 2023-05-16:
Video is in colour (at last - just a dead lm1889 and 74ls123) but picture is very unstable

1) Significant colour bleed
2) Luma level high then low on alternating lines
3) Top of border image is too dark
4) Bottom of border image is light (as in main text area green light)
5) Text background appears to be alternating between colour sets (green and orange)
6) Vertical sync seems poor
7) Horizontal sync is poor at the top of the screen

jimbro1000, 2023-05-16:
Check voltage bias level between R33 and R34, should help to resolve border luma levels
Check output of IC23B (Q = 9, ~Q = 8) and frequency of ~VCLK on output of IC22C (8) and IC29A-Q3 (6) - should be CLK and CLK/16
Adjust RV1 and C7 for best output (compare with D64 repro)

jimbro1000, 2023-05-18:
Swapped R33 and R34 values - approximately same output as D64
Swapped C49 for resistor (6.8K) - output now comparable to D64 but final output is much worse
Output at this point seems to be a lack of clear HS and FS component in output. Pulses are being generated correctly (strength and frequency) so need to look at multiplexing and final combination of output in amp circuit

jimbro1000, 2023-05-20:
Error traced to shorted bodge wires on IC10

Closed 2023-05-20.

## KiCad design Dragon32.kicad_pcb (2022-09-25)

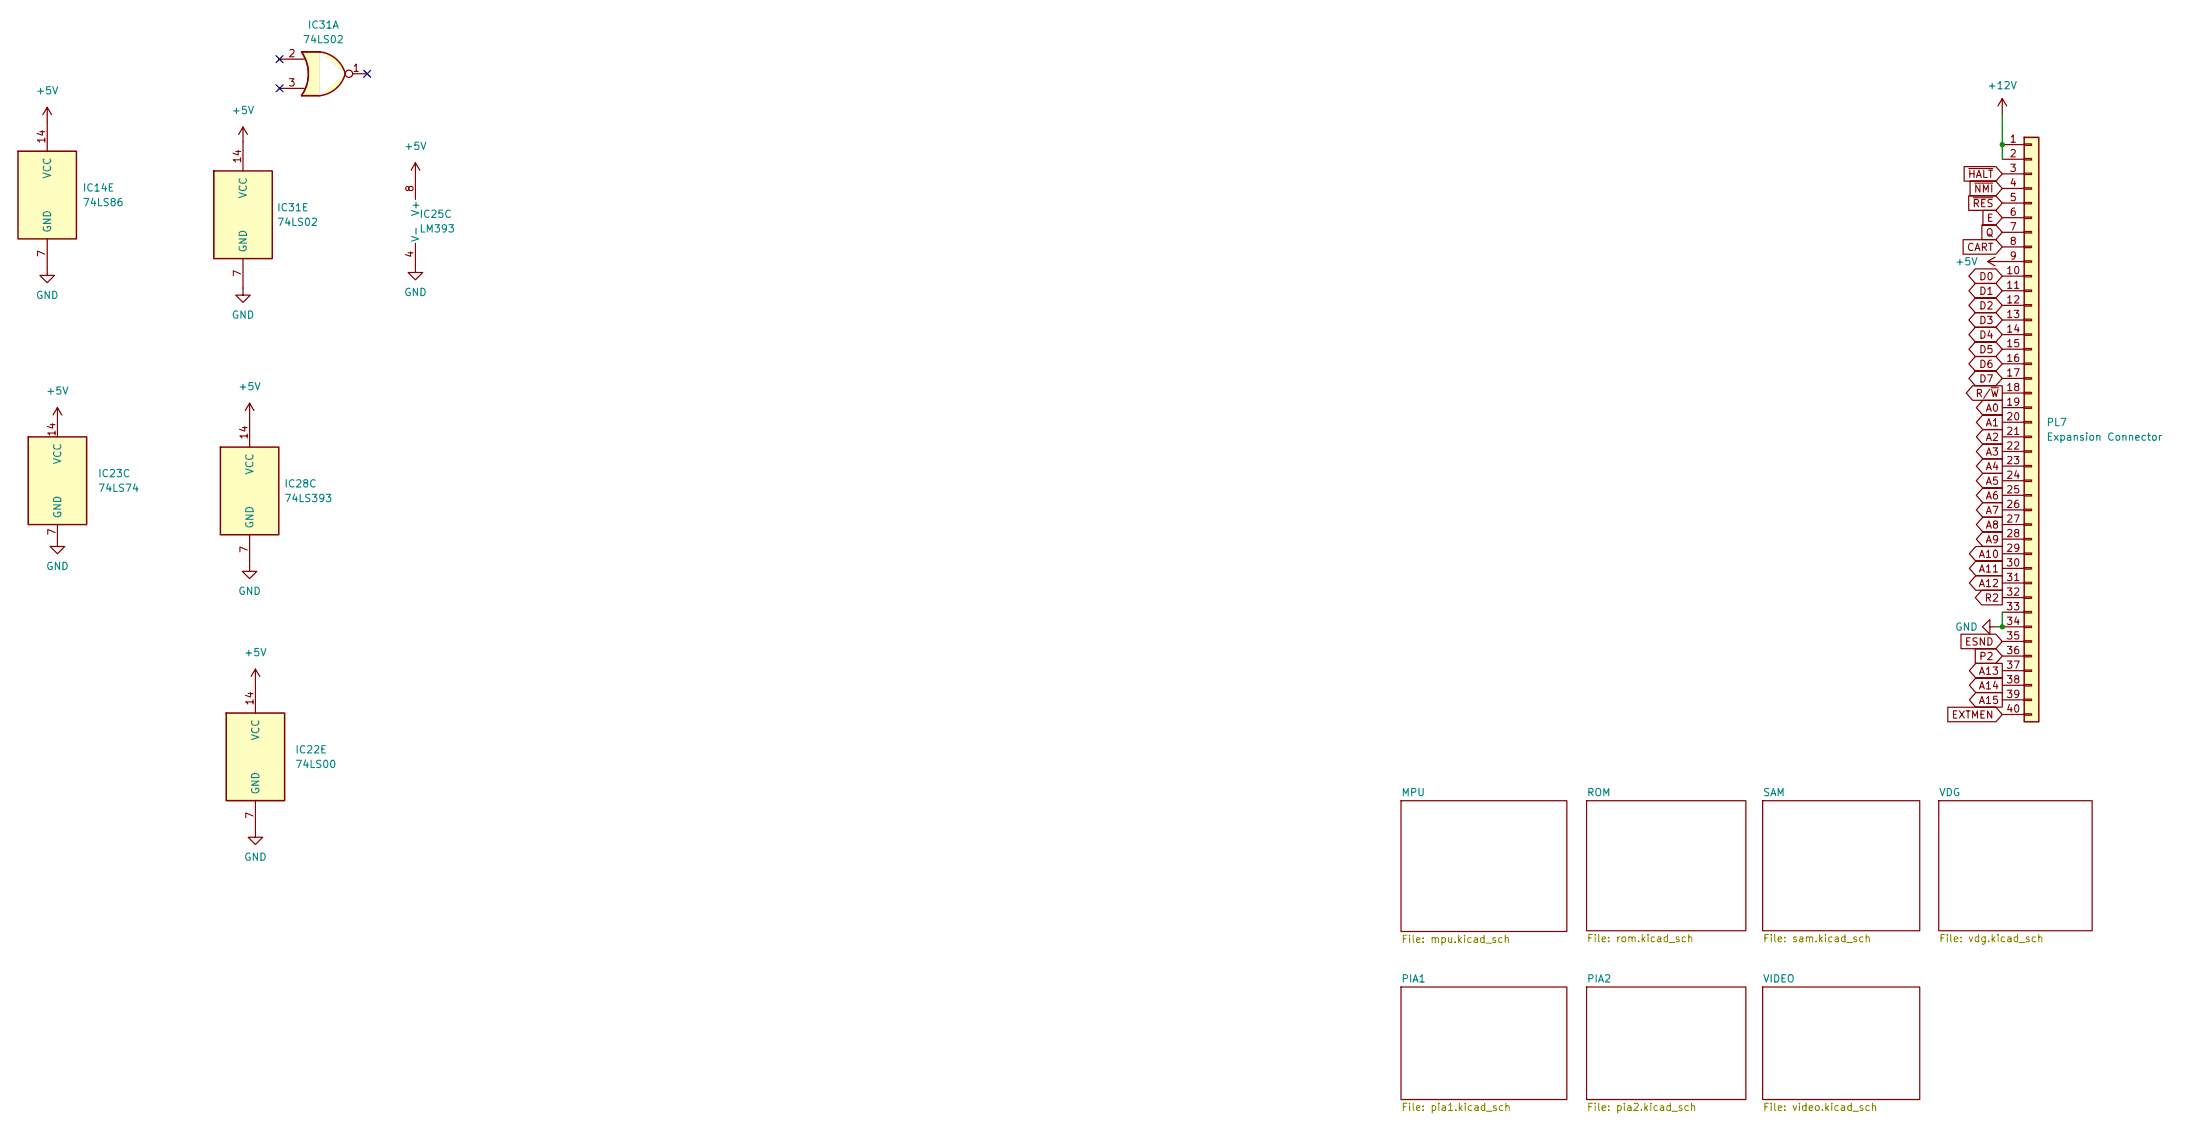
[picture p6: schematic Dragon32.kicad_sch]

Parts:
IC14: 74LS86; DIP-14_W7.62mm
IC22: 74LS00; DIP-14_W7.62mm
IC23: 74LS74; DIP-14_W7.62mm
IC25: LM393; DIP-8_W7.62mm
IC28: 74LS393; DIP-14_W7.62mm
IC31: 74LS02; DIP-14_W7.62mm
PL7: Expansion Connector; Edge_2x20_P2.54mm_Horizontal

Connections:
+5V: IC14.14 (VCC), IC22.14 (VCC), IC23.14 (VCC), IC25.8 (V+), IC28.14 (VCC), IC31.14 (VCC), PL7.9; also elsewhere on the board
+12V: PL7.1, PL7.2; also elsewhere on the board
A0: PL7.19; also elsewhere on the board
A1: PL7.20; also elsewhere on the board
A2: PL7.21; also elsewhere on the board
A3: PL7.22; also elsewhere on the board
A4: PL7.23; also elsewhere on the board
A5: PL7.24; also elsewhere on the board
A6: PL7.25; also elsewhere on the board
A7: PL7.26; also elsewhere on the board
A8: PL7.27; also elsewhere on the board
A9: PL7.28; also elsewhere on the board
A10: PL7.29; also elsewhere on the board
A11: PL7.30; also elsewhere on the board
A12: PL7.31; also elsewhere on the board
A13: PL7.37; also elsewhere on the board
A14: PL7.38; also elsewhere on the board
A15: PL7.39; also elsewhere on the board
CART: PL7.8; also elsewhere on the board
D0: PL7.10; also elsewhere on the board
D1: PL7.11; also elsewhere on the board
D2: PL7.12; also elsewhere on the board
D3: PL7.13; also elsewhere on the board
D4: PL7.14; also elsewhere on the board
D5: PL7.15; also elsewhere on the board
D6: PL7.16; also elsewhere on the board
D7: PL7.17; also elsewhere on the board
E: PL7.6; also elsewhere on the board
ESND: PL7.35; also elsewhere on the board
EXTMEN: PL7.40; also elsewhere on the board
GND: IC14.7 (GND), IC22.7 (GND), IC23.7 (GND), IC25.4 (V-), IC28.7 (GND), IC31.7 (GND), PL7.33, PL7.34; also elsewhere on the board
P2: PL7.36; also elsewhere on the board
Q: PL7.7; also elsewhere on the board
R2: PL7.32; also elsewhere on the board
R/~W: PL7.18; also elsewhere on the board
~HALT: PL7.3; also elsewhere on the board
~NMI: PL7.4; also elsewhere on the board
~RES: PL7.5; also elsewhere on the board

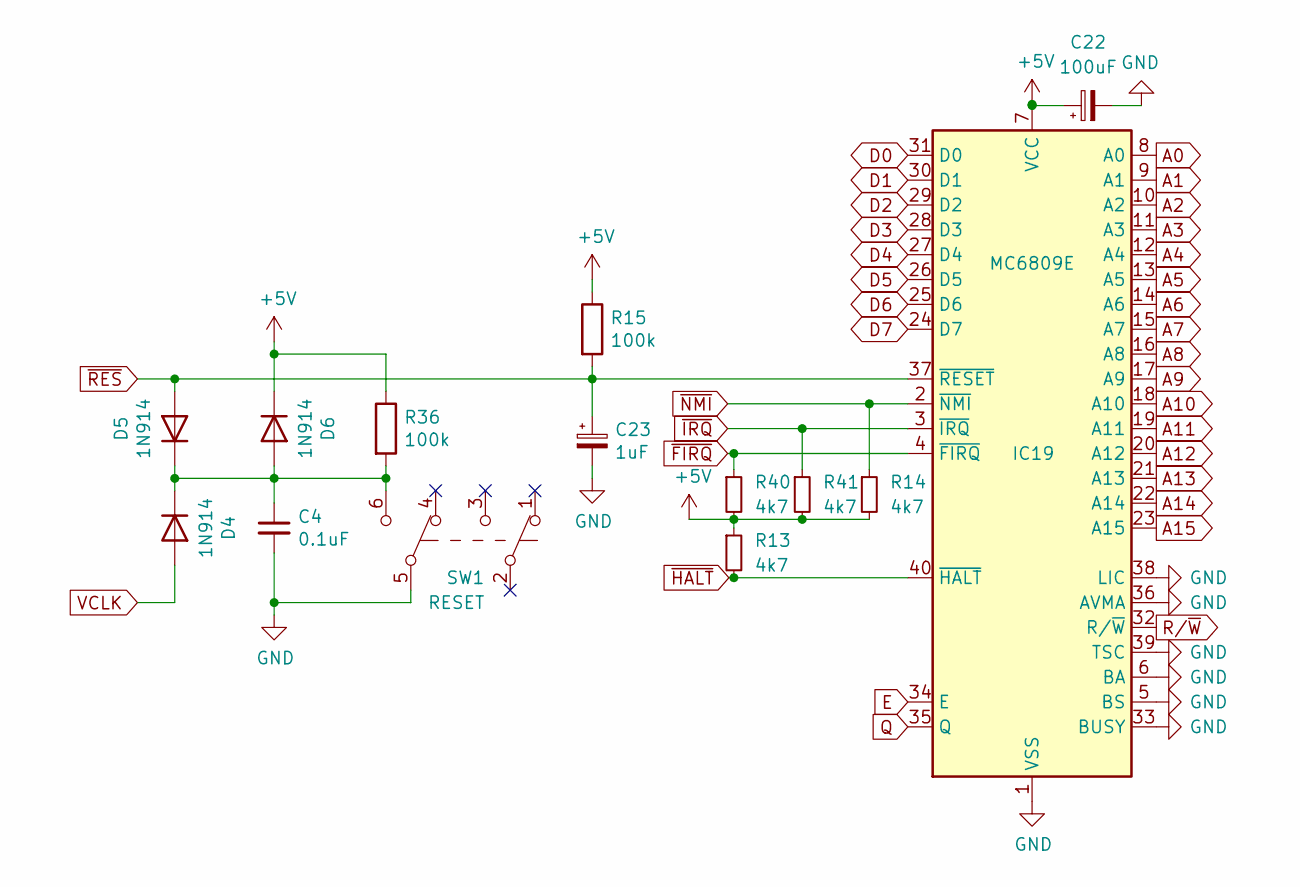
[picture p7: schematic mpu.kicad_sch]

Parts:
C4: 0.1uF; C_Disc_D3.0mm_W2.0mm_P2.50mm
C22: 100uF; CP_Radial_D6.3mm_P2.50mm
C23: 1uF; CP_Radial_D5.0mm_P2.50mm
D4, D5, D6: 1N914; D_DO-35_SOD27_P7.62mm_Horizontal
IC19: MC6809E; DIP-40_W15.24mm
R13, R14, R40, R41: 4k7; R_Axial_DIN0207_L6.3mm_D2.5mm_P10.16mm_Horizontal
R15, R36: 100k; R_Axial_DIN0207_L6.3mm_D2.5mm_P10.16mm_Horizontal
SW1: RESET; Button_AlpsAlpine_SPUN190900

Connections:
+5V: C22.1, D6.1 (K), IC19.7 (VCC), R13.1, R14.2, R15.1, R36.1, R40.2, R41.2; also elsewhere on the board
A0: IC19.8 (A0); also elsewhere on the board
A1: IC19.9 (A1); also elsewhere on the board
A2: IC19.10 (A2); also elsewhere on the board
A3: IC19.11 (A3); also elsewhere on the board
A4: IC19.12 (A4); also elsewhere on the board
A5: IC19.13 (A5); also elsewhere on the board
A6: IC19.14 (A6); also elsewhere on the board
A7: IC19.15 (A7); also elsewhere on the board
A8: IC19.16 (A8); also elsewhere on the board
A9: IC19.17 (A9); also elsewhere on the board
A10: IC19.18 (A10); also elsewhere on the board
A11: IC19.19 (A11); also elsewhere on the board
A12: IC19.20 (A12); also elsewhere on the board
A13: IC19.21 (A13); also elsewhere on the board
A14: IC19.22 (A14); also elsewhere on the board
A15: IC19.23 (A15); also elsewhere on the board
D0: IC19.31 (D0); also elsewhere on the board
D1: IC19.30 (D1); also elsewhere on the board
D2: IC19.29 (D2); also elsewhere on the board
D3: IC19.28 (D3); also elsewhere on the board
D4: IC19.27 (D4); also elsewhere on the board
D5: IC19.26 (D5); also elsewhere on the board
D6: IC19.25 (D6); also elsewhere on the board
D7: IC19.24 (D7); also elsewhere on the board
E: IC19.34 (E); also elsewhere on the board
GND: C4.2, C22.2, C23.2, IC19.1 (VSS), IC19.5 (BS), IC19.6 (BA), IC19.33 (BUSY), IC19.36 (AVMA), IC19.38 (LIC), IC19.39 (TSC), SW1.5 (B); also elsewhere on the board
unnamed: C4.1, D4.1 (K), D5.1 (K), D6.2 (A), R36.2, SW1.6 (C)
Q: IC19.35 (Q); also elsewhere on the board
R/~W: IC19.32 (R/~W); also elsewhere on the board
VCLK: D4.2 (A); also elsewhere on the board
~FIRQ: IC19.4 (~FIRQ), R40.1; also elsewhere on the board
~HALT: IC19.40 (~HALT), R13.2; also elsewhere on the board
~IRQ: IC19.3 (~IRQ), R41.1; also elsewhere on the board
~NMI: IC19.2 (~NMI), R14.1; also elsewhere on the board
~RES: C23.1, D5.2 (A), IC19.37 (~RESET), R15.2; also elsewhere on the board

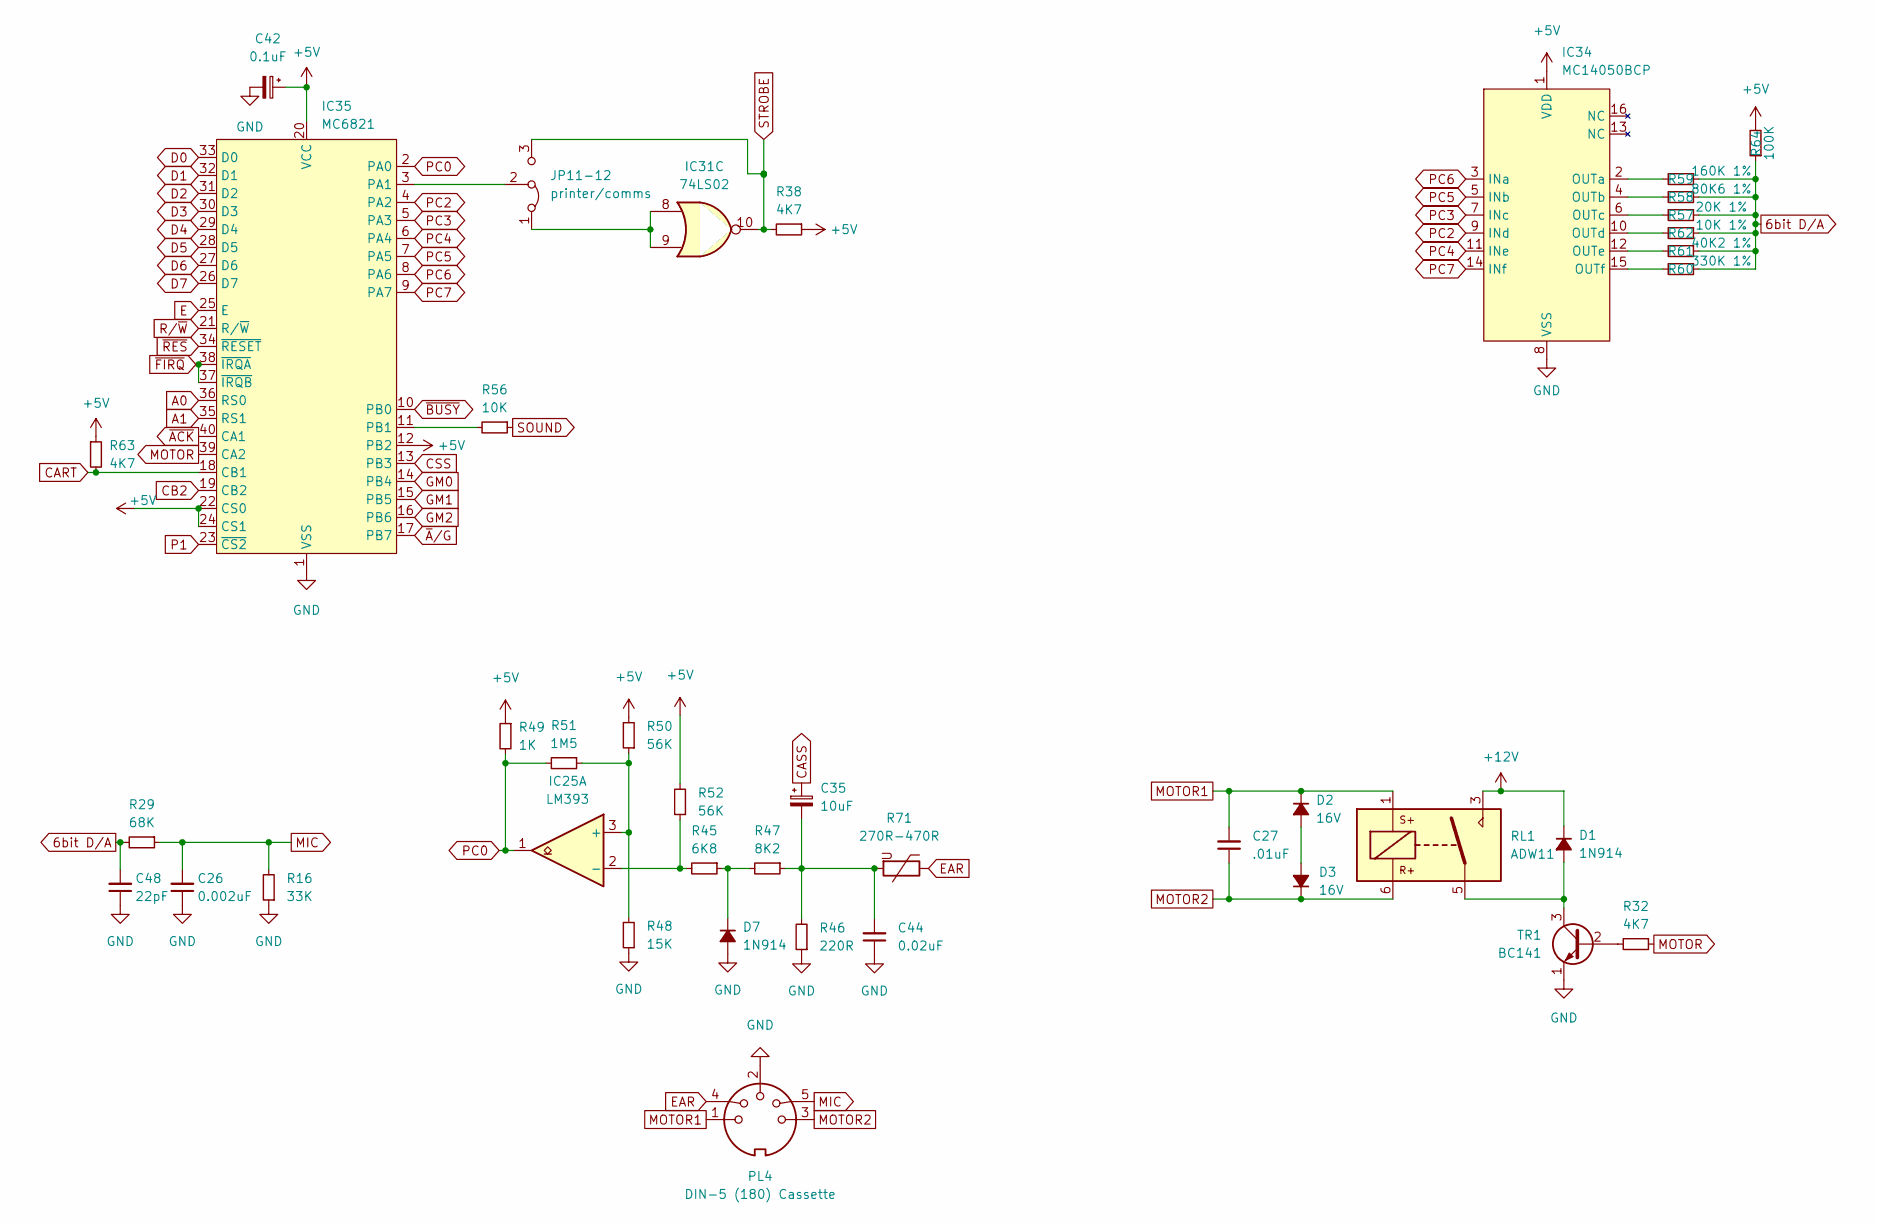
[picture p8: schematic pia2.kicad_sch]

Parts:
C26: 0.002uF; C_Disc_D3.0mm_W2.0mm_P2.50mm
C27: .01uF; C_Disc_D3.0mm_W2.0mm_P2.50mm
C35: 10uF; CP_Radial_D5.0mm_P2.50mm
C42: 0.1uF; CP_Radial_D5.0mm_P2.50mm
C44: 0.02uF; C_Disc_D3.0mm_W2.0mm_P2.50mm
C48: 22pF; C_Disc_D3.0mm_W2.0mm_P2.50mm
D1, D7: 1N914; D_DO-35_SOD27_P7.62mm_Horizontal
D2, D3: 16V; D_DO-35_SOD27_P7.62mm_Horizontal
IC25: LM393; DIP-8_W7.62mm
IC31: 74LS02; DIP-14_W7.62mm
IC34: MC14050BCP; DIP-16_W7.62mm
IC35: MC6821; DIP-40_W15.24mm
JP11-12: printer/comms; PinHeader_1x03_P2.54mm_Vertical
PL4: DIN-5 (180) Cassette; DIN-5_DELTRON_671-0501_45deg_Horizontal
R16: 33K; R_Axial_DIN0207_L6.3mm_D2.5mm_P10.16mm_Horizontal
R29: 68K; R_Axial_DIN0207_L6.3mm_D2.5mm_P10.16mm_Horizontal
R32, R38, R63: 4K7; R_Axial_DIN0207_L6.3mm_D2.5mm_P10.16mm_Horizontal
R45: 6K8; R_Axial_DIN0207_L6.3mm_D2.5mm_P10.16mm_Horizontal
R46: 220R; R_Axial_DIN0207_L6.3mm_D2.5mm_P10.16mm_Horizontal
R47: 8K2; R_Axial_DIN0207_L6.3mm_D2.5mm_P10.16mm_Horizontal
R48: 15K; R_Axial_DIN0207_L6.3mm_D2.5mm_P10.16mm_Horizontal
R49: 1K; R_Axial_DIN0207_L6.3mm_D2.5mm_P10.16mm_Horizontal
R50, R52: 56K; R_Axial_DIN0207_L6.3mm_D2.5mm_P10.16mm_Horizontal
R51: 1M5; R_Axial_DIN0207_L6.3mm_D2.5mm_P10.16mm_Horizontal
R56: 10K; R_Axial_DIN0207_L6.3mm_D2.5mm_P10.16mm_Horizontal
R57: 20K 1%; R_Axial_DIN0207_L6.3mm_D2.5mm_P10.16mm_Horizontal
R58: 80K6 1%; R_Axial_DIN0207_L6.3mm_D2.5mm_P10.16mm_Horizontal
R59: 160K 1%; R_Axial_DIN0207_L6.3mm_D2.5mm_P10.16mm_Horizontal
R60: 330K 1%; R_Axial_DIN0207_L6.3mm_D2.5mm_P10.16mm_Horizontal
R61: 40K2 1%; R_Axial_DIN0207_L6.3mm_D2.5mm_P10.16mm_Horizontal
R62: 10K 1%; R_Axial_DIN0207_L6.3mm_D2.5mm_P10.16mm_Horizontal
R64: 100K; R_Axial_DIN0207_L6.3mm_D2.5mm_P10.16mm_Horizontal
R71: 270R-470R; RV_Disc_D7mm_W3.4mm_P5mm
RL1: ADW11; Relay_1P1T_NO_10x24x18.8mm_Panasonic_ADW11xxxxW_THT
TR1: BC141; TO-92_Inline

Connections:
6bit D/A: C48.2, R29.2, R57.1, R58.1, R59.1, R60.1, R61.1, R62.1, R64.1; also elsewhere on the board
+5V: C42.1, IC34.1 (VDD), IC35.12 (PB2), IC35.20 (VCC), IC35.22 (CS0), IC35.24 (CS1), R38.1, R49.1, R50.2, R52.2, R63.1, R64.2; also elsewhere on the board
+12V: D1.1 (K), RL1.3; also elsewhere on the board
A0: IC35.36 (RS0); also elsewhere on the board
A1: IC35.35 (RS1); also elsewhere on the board
CART: IC35.18 (CB1), R63.2; also elsewhere on the board
CASS: C35.1; also elsewhere on the board
CB2: IC35.19 (CB2)
CSS: IC35.13 (PB3); also elsewhere on the board
D0: IC35.33 (D0); also elsewhere on the board
D1: IC35.32 (D1); also elsewhere on the board
D2: IC35.31 (D2); also elsewhere on the board
D3: IC35.30 (D3); also elsewhere on the board
D4: IC35.29 (D4); also elsewhere on the board
D5: IC35.28 (D5); also elsewhere on the board
D6: IC35.27 (D6); also elsewhere on the board
D7: IC35.26 (D7); also elsewhere on the board
E: IC35.25 (E); also elsewhere on the board
EAR: PL4.4, R71.1
GM0: IC35.14 (PB4); also elsewhere on the board
GM1: IC35.15 (PB5); also elsewhere on the board
GM2: IC35.16 (PB6); also elsewhere on the board
GND: C26.1, C42.2, C44.1, C48.1, D7.2 (A), IC34.8 (VSS), IC35.1 (VSS), PL4.2, R16.1, R46.1, R48.1, TR1.1 (E); also elsewhere on the board
MIC: C26.2, PL4.5, R16.2, R29.1
MOTOR: IC35.39 (CA2), R32.1
MOTOR1: C27.2, D2.1 (K), PL4.1, RL1.1
MOTOR2: C27.1, D3.1 (K), PL4.3, RL1.6
unnamed: C35.2, C44.2, R46.2, R47.1, R71.2
unnamed: D1.2 (A), RL1.5, TR1.3 (C)
unnamed: D2.2 (A), D3.2 (A)
unnamed: D7.1 (K), R45.1, R47.2
unnamed: IC25.2 (-), R45.2, R52.1
unnamed: IC25.3 (+), R48.2, R50.1, R51.1
unnamed: IC31.8, IC31.9, JP11-12.1 (A)
unnamed: IC34.2 (OUTa), R59.2
unnamed: IC34.4 (OUTb), R58.2
unnamed: IC34.6 (OUTc), R57.2
unnamed: IC34.10 (OUTd), R62.2
unnamed: IC34.12 (OUTe), R61.2
unnamed: IC34.15 (OUTf), R60.2
unnamed: IC35.3 (PA1), JP11-12.2 (C)
unnamed: IC35.11 (PB1), R56.2
unnamed: R32.2, TR1.2 (B)
P1: IC35.23 (~CS2); also elsewhere on the board
PC0: IC25.1, IC35.2 (PA0), R49.2, R51.2
PC2: IC34.9 (INd), IC35.4 (PA2)
PC3: IC34.7 (INc), IC35.5 (PA3)
PC4: IC34.11 (INe), IC35.6 (PA4)
PC5: IC34.5 (INb), IC35.7 (PA5)
PC6: IC34.3 (INa), IC35.8 (PA6)
PC7: IC34.14 (INf), IC35.9 (PA7)
R/~W: IC35.21 (R/~W); also elsewhere on the board
SOUND: R56.1; also elsewhere on the board
STROBE: IC31.10, JP11-12.3 (B), R38.2; also elsewhere on the board
~ACK: IC35.40 (CA1); also elsewhere on the board
~A/G: IC35.17 (PB7); also elsewhere on the board
~BUSY: IC35.10 (PB0); also elsewhere on the board
~FIRQ: IC35.37 (~IRQB), IC35.38 (~IRQA); also elsewhere on the board
~RES: IC35.34 (~RESET); also elsewhere on the board

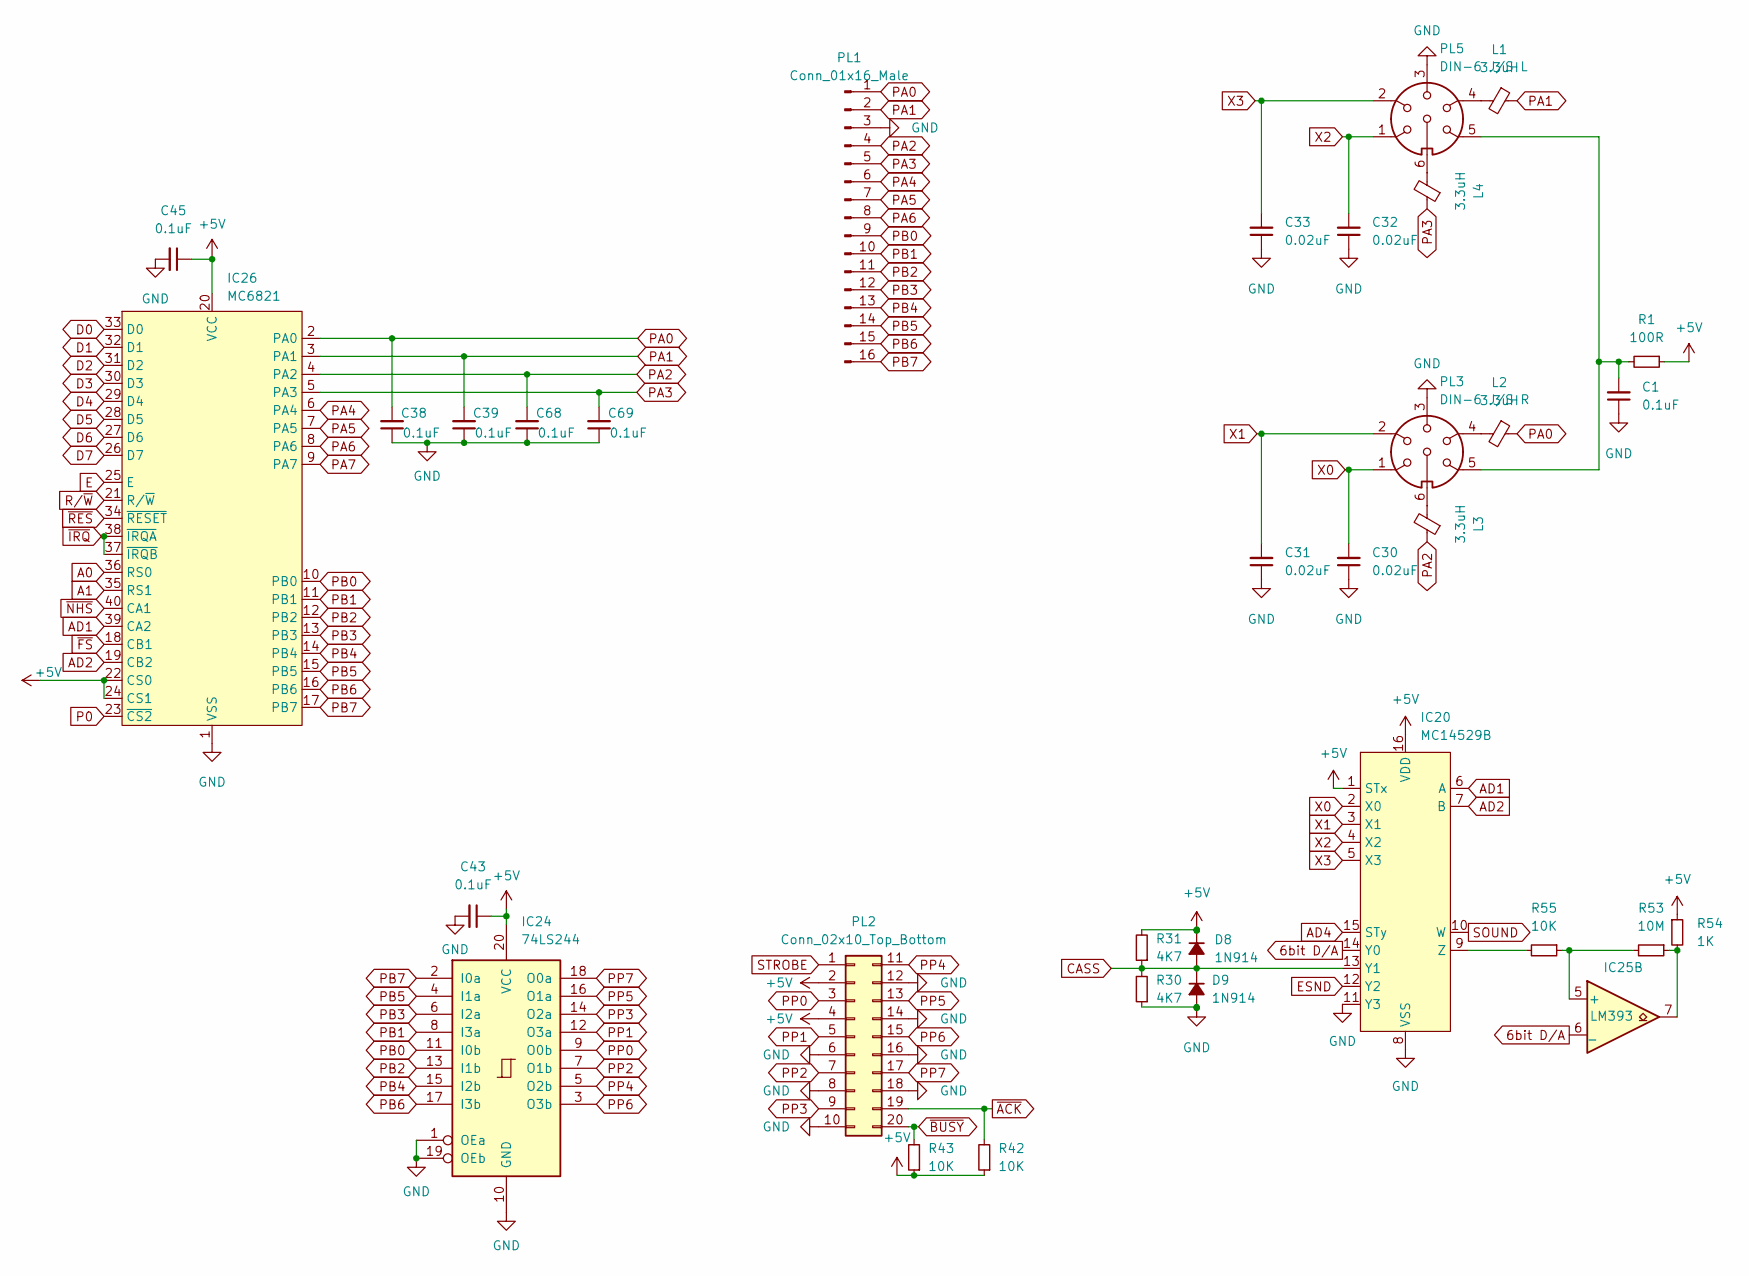
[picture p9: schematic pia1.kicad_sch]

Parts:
C1, C38, C39, C43, C45, C68, C69: 0.1uF; C_Disc_D3.0mm_W2.0mm_P2.50mm
C30, C31, C32, C33: 0.02uF; C_Disc_D3.0mm_W2.0mm_P2.50mm
D8, D9: 1N914; D_DO-35_SOD27_P7.62mm_Horizontal
IC20: MC14529B; DIP-16_W7.62mm
IC24: 74LS244; DIP-20_W7.62mm
IC25: LM393; DIP-8_W7.62mm
IC26: MC6821; DIP-40_W15.24mm
L1, L2, L3, L4: 3.3uH; L_Axial_L7.0mm_D3.3mm_P10.16mm_Horizontal_Fastron_MICC
PL1: Conn_01x16_Male; PinHeader_1x16_P2.54mm_Vertical
PL2: Conn_02x10_Top_Bottom; IDC-Header_2x10-1MP_P2.54mm_Latch_Horizontal
PL3: DIN-6 J/S R; DIN-6_DELTRON_671-0601_Horizontal
PL5: DIN-6 J/S L; DIN-6_DELTRON_671-0601_Horizontal
R1: 100R; R_Axial_DIN0207_L6.3mm_D2.5mm_P10.16mm_Horizontal
R30, R31: 4K7; R_Axial_DIN0207_L6.3mm_D2.5mm_P10.16mm_Horizontal
R42, R43, R55: 10K; R_Axial_DIN0207_L6.3mm_D2.5mm_P10.16mm_Horizontal
R53: 10M; R_Axial_DIN0207_L6.3mm_D2.5mm_P10.16mm_Horizontal
R54: 1K; R_Axial_DIN0207_L6.3mm_D2.5mm_P10.16mm_Horizontal

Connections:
6bit D/A: IC20.14 (Y0), IC25.6 (_); also elsewhere on the board
+5V: C43.1, C45.1, D8.1 (K), IC20.1 (STx), IC20.16 (VDD), IC24.20 (VCC), IC26.20 (VCC), IC26.22 (CS0), IC26.24 (CS1), PL2.2, PL2.4, R1.1, R31.2, R42.1, R43.1, R54.1; also elsewhere on the board
A0: IC26.36 (RS0); also elsewhere on the board
A1: IC26.35 (RS1); also elsewhere on the board
AD1: IC20.6 (A), IC26.39 (CA2)
AD2: IC20.7 (B), IC26.19 (CB2)
AD4: IC20.15 (STy)
CASS: D8.2 (A), D9.1 (K), IC20.13 (Y1), R30.2, R31.1; also elsewhere on the board
D0: IC26.33 (D0); also elsewhere on the board
D1: IC26.32 (D1); also elsewhere on the board
D2: IC26.31 (D2); also elsewhere on the board
D3: IC26.30 (D3); also elsewhere on the board
D4: IC26.29 (D4); also elsewhere on the board
D5: IC26.28 (D5); also elsewhere on the board
D6: IC26.27 (D6); also elsewhere on the board
D7: IC26.26 (D7); also elsewhere on the board
E: IC26.25 (E); also elsewhere on the board
ESND: IC20.12 (Y2); also elsewhere on the board
GND: C1.1, C30.1, C31.1, C32.1, C33.1, C38.1, C39.1, C43.2, C45.2, C68.1, C69.1, D9.2 (A), IC20.8 (VSS), IC20.11 (Y3), IC24.1 (OEa), IC24.10 (GND), IC24.19 (OEb), IC26.1 (VSS), PL1.3, PL2.6, PL2.8, PL2.10, PL2.12, PL2.14, PL2.16, PL2.18, PL3.3, PL5.3, R30.1; also elsewhere on the board
unnamed: C1.2, PL3.5, PL5.5, R1.2
unnamed: IC20.9 (Z), R55.2
unnamed: IC25.5 (+), R53.2, R55.1
unnamed: IC25.7, R53.1, R54.2
unnamed: L1.2, PL5.4
unnamed: L2.2, PL3.4
unnamed: L3.2, PL3.6
unnamed: L4.2, PL5.6
P0: IC26.23 (~CS2); also elsewhere on the board
PA0: C38.2, IC26.2 (PA0), L2.1, PL1.1
PA1: C39.2, IC26.3 (PA1), L1.1, PL1.2
PA2: C68.2, IC26.4 (PA2), L3.1, PL1.4
PA3: C69.2, IC26.5 (PA3), L4.1, PL1.5
PA4: IC26.6 (PA4), PL1.6
PA5: IC26.7 (PA5), PL1.7
PA6: IC26.8 (PA6), PL1.8
PA7: IC26.9 (PA7)
PB0: IC24.11 (I0b), IC26.10 (PB0), PL1.9
PB1: IC24.8 (I3a), IC26.11 (PB1), PL1.10
PB2: IC24.13 (I1b), IC26.12 (PB2), PL1.11
PB3: IC24.6 (I2a), IC26.13 (PB3), PL1.12
PB4: IC24.15 (I2b), IC26.14 (PB4), PL1.13
PB5: IC24.4 (I1a), IC26.15 (PB5), PL1.14
PB6: IC24.17 (I3b), IC26.16 (PB6), PL1.15
PB7: IC24.2 (I0a), IC26.17 (PB7), PL1.16
PP0: IC24.9 (O0b), PL2.3
PP1: IC24.12 (O3a), PL2.5
PP2: IC24.7 (O1b), PL2.7
PP3: IC24.14 (O2a), PL2.9
PP4: IC24.5 (O2b), PL2.11
PP5: IC24.16 (O1a), PL2.13
PP6: IC24.3 (O3b), PL2.15
PP7: IC24.18 (O0a), PL2.17
R/~W: IC26.21 (R/~W); also elsewhere on the board
SOUND: IC20.10 (W); also elsewhere on the board
STROBE: PL2.1; also elsewhere on the board
X0: C30.2, IC20.2 (X0), PL3.1
X1: C31.2, IC20.3 (X1), PL3.2
X2: C32.2, IC20.4 (X2), PL5.1
X3: C33.2, IC20.5 (X3), PL5.2
~ACK: PL2.19, R42.2; also elsewhere on the board
~BUSY: PL2.20, R43.2; also elsewhere on the board
~FS: IC26.18 (CB1); also elsewhere on the board
~IRQ: IC26.37 (~IRQB), IC26.38 (~IRQA); also elsewhere on the board
~NHS: IC26.40 (CA1); also elsewhere on the board
~RES: IC26.34 (~RESET); also elsewhere on the board

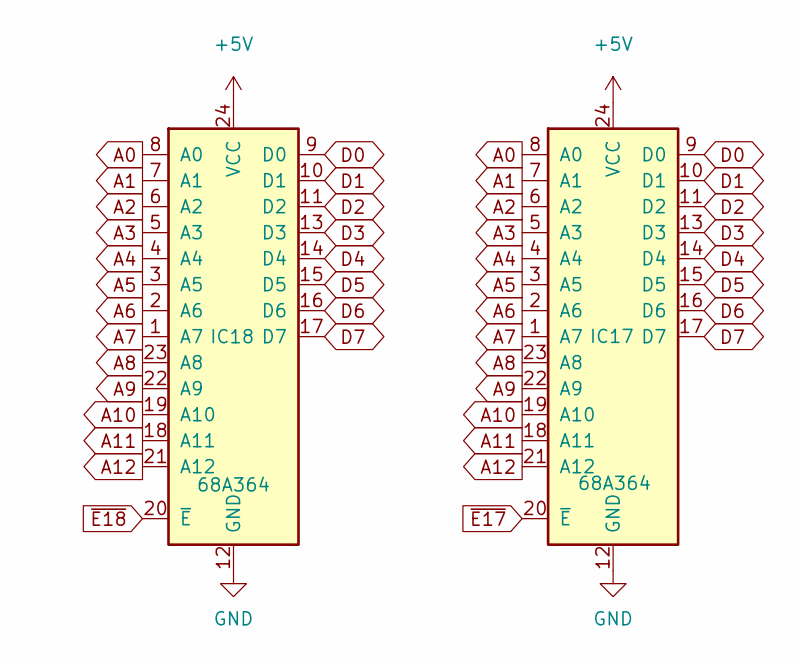
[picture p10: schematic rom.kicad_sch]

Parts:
IC17, IC18: 68A364; DIP-24_W15.24mm

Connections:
+5V: IC17.24 (VCC), IC18.24 (VCC); also elsewhere on the board
A0: IC17.8 (A0), IC18.8 (A0); also elsewhere on the board
A1: IC17.7 (A1), IC18.7 (A1); also elsewhere on the board
A2: IC17.6 (A2), IC18.6 (A2); also elsewhere on the board
A3: IC17.5 (A3), IC18.5 (A3); also elsewhere on the board
A4: IC17.4 (A4), IC18.4 (A4); also elsewhere on the board
A5: IC17.3 (A5), IC18.3 (A5); also elsewhere on the board
A6: IC17.2 (A6), IC18.2 (A6); also elsewhere on the board
A7: IC17.1 (A7), IC18.1 (A7); also elsewhere on the board
A8: IC17.23 (A8), IC18.23 (A8); also elsewhere on the board
A9: IC17.22 (A9), IC18.22 (A9); also elsewhere on the board
A10: IC17.19 (A10), IC18.19 (A10); also elsewhere on the board
A11: IC17.18 (A11), IC18.18 (A11); also elsewhere on the board
A12: IC17.21 (A12), IC18.21 (A12); also elsewhere on the board
D0: IC17.9 (D0), IC18.9 (D0); also elsewhere on the board
D1: IC17.10 (D1), IC18.10 (D1); also elsewhere on the board
D2: IC17.11 (D2), IC18.11 (D2); also elsewhere on the board
D3: IC17.13 (D3), IC18.13 (D3); also elsewhere on the board
D4: IC17.14 (D4), IC18.14 (D4); also elsewhere on the board
D5: IC17.15 (D5), IC18.15 (D5); also elsewhere on the board
D6: IC17.16 (D6), IC18.16 (D6); also elsewhere on the board
D7: IC17.17 (D7), IC18.17 (D7); also elsewhere on the board
GND: IC17.12 (GND), IC18.12 (GND); also elsewhere on the board
~E17: IC17.20 (~E); also elsewhere on the board
~E18: IC18.20 (~E); also elsewhere on the board

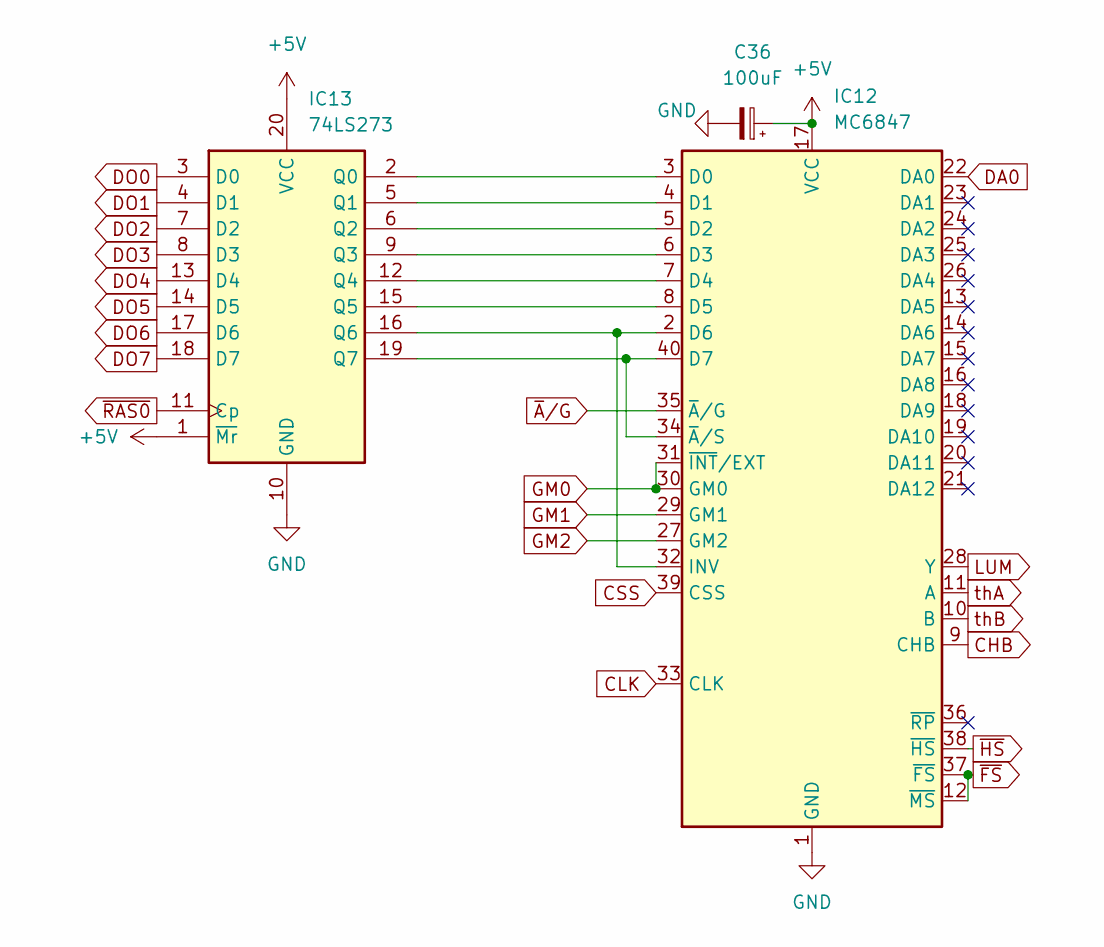
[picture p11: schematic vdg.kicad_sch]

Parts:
C36: 100uF; CP_Radial_D7.5mm_P2.50mm
IC12: MC6847; DIP-40_W15.24mm
IC13: 74LS273; DIP-20_W7.62mm

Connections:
+5V: C36.1, IC12.17 (VCC), IC13.1 (~Mr), IC13.20 (VCC); also elsewhere on the board
CHB: IC12.9 (CHB); also elsewhere on the board
CLK: IC12.33 (CLK); also elsewhere on the board
CSS: IC12.39 (CSS); also elsewhere on the board
DA0: IC12.22 (DA0); also elsewhere on the board
DO0: IC13.3 (D0); also elsewhere on the board
DO1: IC13.4 (D1); also elsewhere on the board
DO2: IC13.7 (D2); also elsewhere on the board
DO3: IC13.8 (D3); also elsewhere on the board
DO4: IC13.13 (D4); also elsewhere on the board
DO5: IC13.14 (D5); also elsewhere on the board
DO6: IC13.17 (D6); also elsewhere on the board
DO7: IC13.18 (D7); also elsewhere on the board
GM0: IC12.30 (GM0), IC12.31 (~INT/EXT); also elsewhere on the board
GM1: IC12.29 (GM1); also elsewhere on the board
GM2: IC12.27 (GM2); also elsewhere on the board
GND: C36.2, IC12.1 (GND), IC13.10 (GND); also elsewhere on the board
LUM: IC12.28 (Y); also elsewhere on the board
unnamed: IC12.2 (D6), IC12.32 (INV), IC13.16 (Q6)
unnamed: IC12.3 (D0), IC13.2 (Q0)
unnamed: IC12.4 (D1), IC13.5 (Q1)
unnamed: IC12.5 (D2), IC13.6 (Q2)
unnamed: IC12.6 (D3), IC13.9 (Q3)
unnamed: IC12.7 (D4), IC13.12 (Q4)
unnamed: IC12.8 (D5), IC13.15 (Q5)
unnamed: IC12.34 (~A/S), IC12.40 (D7), IC13.19 (Q7)
thA: IC12.11 (A); also elsewhere on the board
thB: IC12.10 (B); also elsewhere on the board
~A/G: IC12.35 (~A/G); also elsewhere on the board
~FS: IC12.12 (~MS), IC12.37 (~FS); also elsewhere on the board
~HS: IC12.38 (~HS); also elsewhere on the board
~RAS0: IC13.11 (Cp); also elsewhere on the board

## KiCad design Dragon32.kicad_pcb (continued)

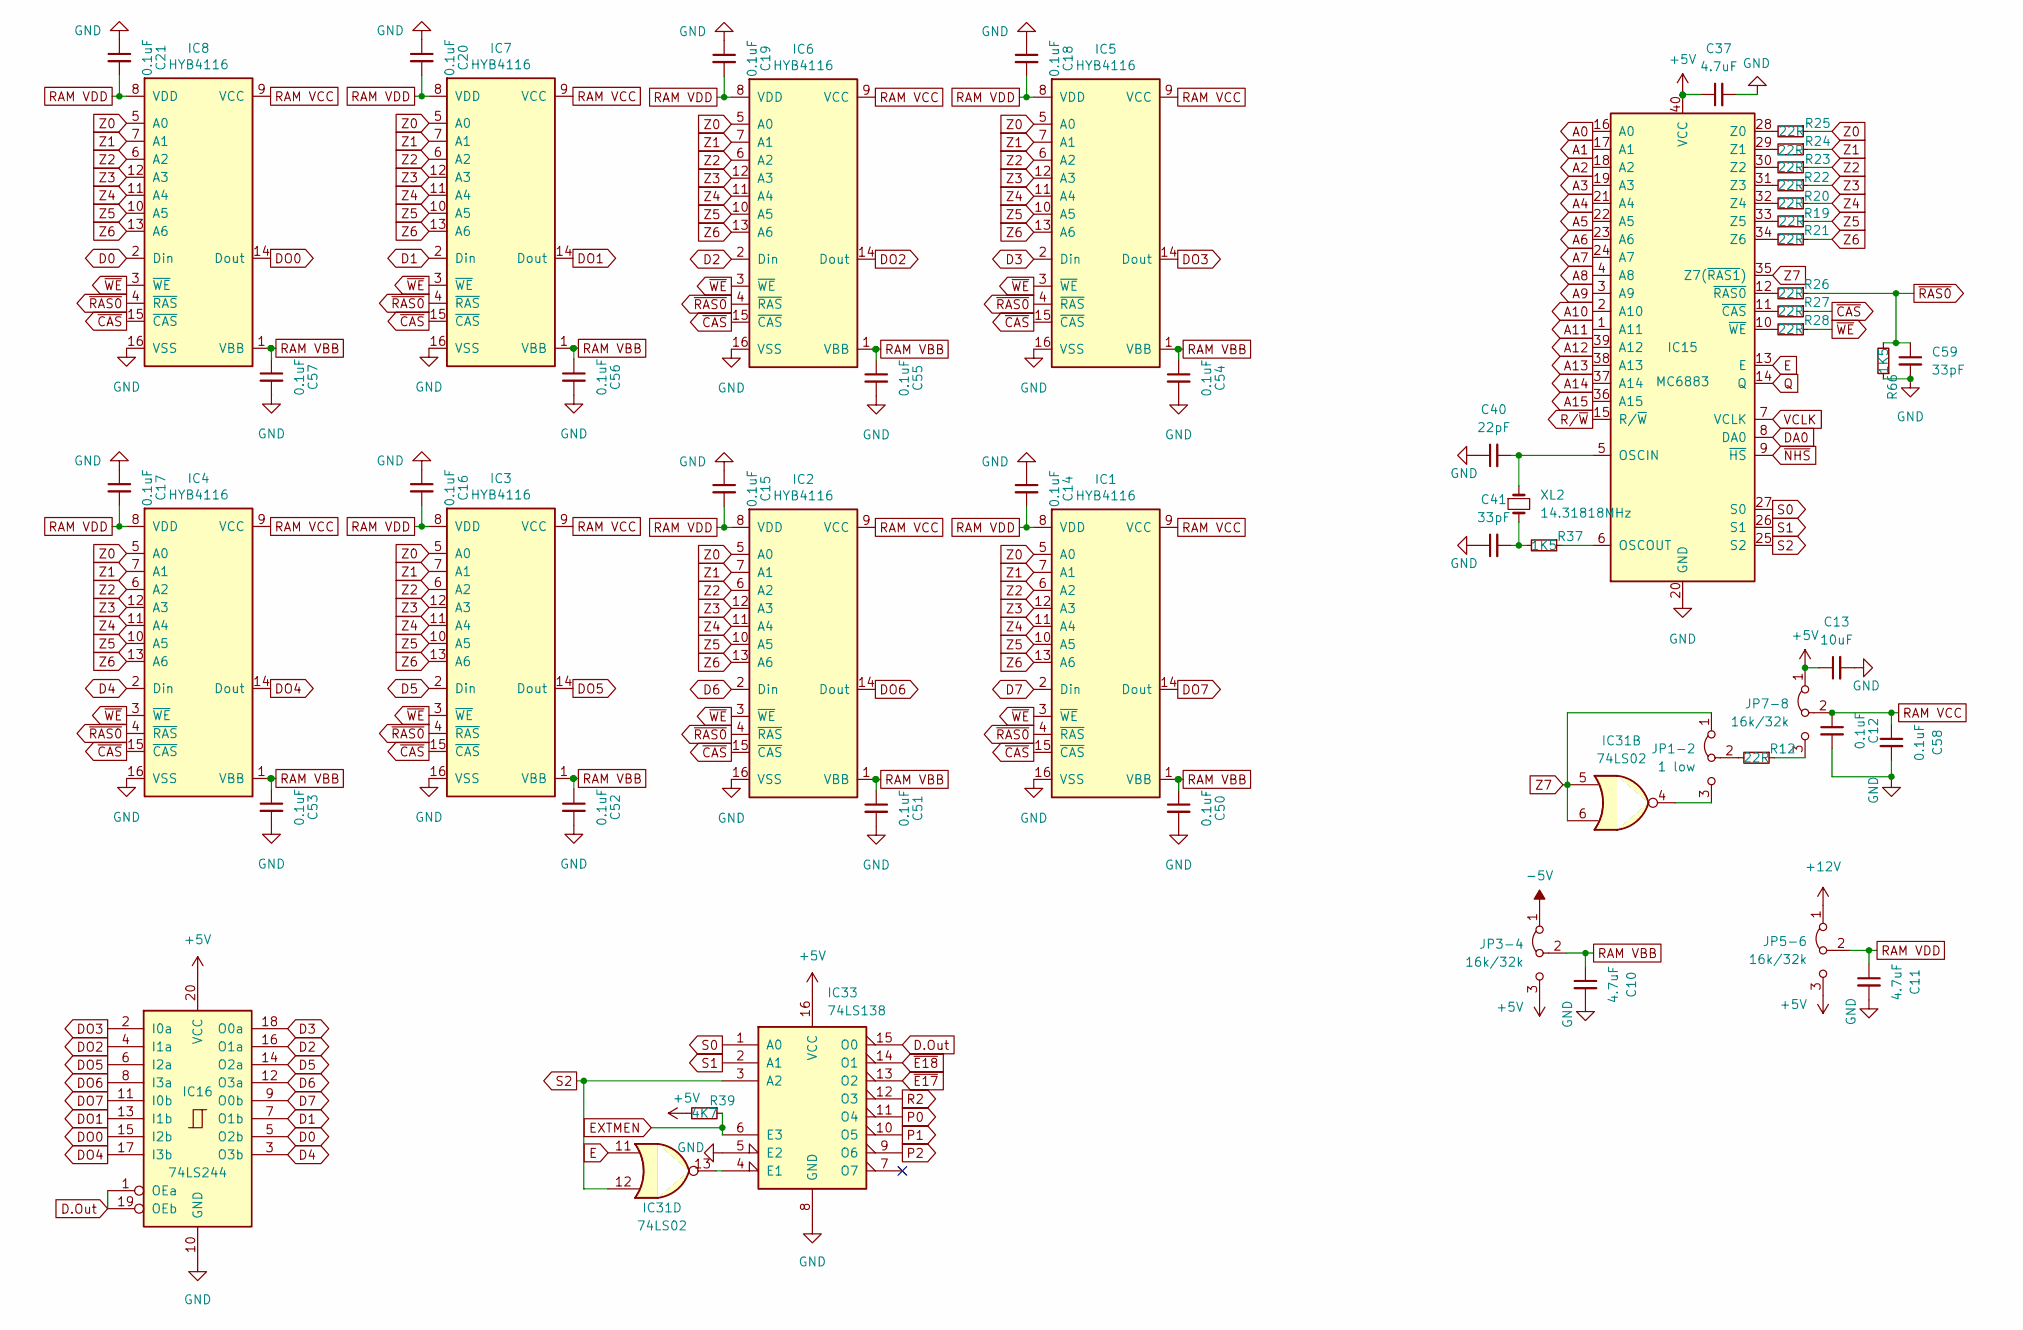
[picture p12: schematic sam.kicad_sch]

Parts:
C10, C11, C37: 4.7uF; C_Disc_D3.0mm_W2.0mm_P2.50mm
C12, C14, C15, C16, C17, C18, C19, C20, C21, C50, C51, C52, C53, C54, C55, C56, C57, C58: 0.1uF; C_Disc_D3.0mm_W2.0mm_P2.50mm
C13: 10uF; C_Disc_D3.0mm_W2.0mm_P2.50mm
C40: 22pF; C_Disc_D3.0mm_W2.0mm_P2.50mm
C41, C59: 33pF; C_Disc_D3.0mm_W2.0mm_P2.50mm
IC1, IC2, IC3, IC4, IC5, IC6, IC7, IC8: HYB4116; DIP-16_W7.62mm
IC15: MC6883; DIP-40_W15.24mm
IC16: 74LS244; DIP-20_W7.62mm
IC31: 74LS02; DIP-14_W7.62mm
IC33: 74LS138; DIP-16_W7.62mm
JP1-2: 1 low; PinHeader_1x03_P2.54mm_Vertical
JP3-4, JP5-6, JP7-8: 16k/32k; PinHeader_1x03_P2.54mm_Vertical
R12, R19, R20, R21, R22, R23, R24, R25, R26, R27, R28: 22R; R_Axial_DIN0207_L6.3mm_D2.5mm_P10.16mm_Horizontal
R37, R66: 1K5; R_Axial_DIN0207_L6.3mm_D2.5mm_P10.16mm_Horizontal
R39: 4K7; R_Axial_DIN0207_L6.3mm_D2.5mm_P10.16mm_Horizontal
XL2: 14.31818MHz; Crystal_HC18-U_Horizontal

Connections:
+5V: C13.1, C37.1, IC15.40 (VCC), IC16.20 (VCC), IC33.16 (VCC), JP3-4.3 (B), JP5-6.3 (B), JP7-8.1 (A), R39.2; also elsewhere on the board
+12V: JP5-6.1 (A); also elsewhere on the board
-5V: JP3-4.1 (A); also elsewhere on the board
A0: IC15.16 (A0); also elsewhere on the board
A1: IC15.17 (A1); also elsewhere on the board
A2: IC15.18 (A2); also elsewhere on the board
A3: IC15.19 (A3); also elsewhere on the board
A4: IC15.21 (A4); also elsewhere on the board
A5: IC15.22 (A5); also elsewhere on the board
A6: IC15.23 (A6); also elsewhere on the board
A7: IC15.24 (A7); also elsewhere on the board
A8: IC15.4 (A8); also elsewhere on the board
A9: IC15.3 (A9); also elsewhere on the board
A10: IC15.2 (A10); also elsewhere on the board
A11: IC15.1 (A11); also elsewhere on the board
A12: IC15.39 (A12); also elsewhere on the board
A13: IC15.38 (A13); also elsewhere on the board
A14: IC15.37 (A14); also elsewhere on the board
A15: IC15.36 (A15); also elsewhere on the board
D0: IC8.2 (Din), IC16.5 (O2b); also elsewhere on the board
D1: IC7.2 (Din), IC16.7 (O1b); also elsewhere on the board
D2: IC6.2 (Din), IC16.16 (O1a); also elsewhere on the board
D3: IC5.2 (Din), IC16.18 (O0a); also elsewhere on the board
D4: IC4.2 (Din), IC16.3 (O3b); also elsewhere on the board
D5: IC3.2 (Din), IC16.14 (O2a); also elsewhere on the board
D6: IC2.2 (Din), IC16.12 (O3a); also elsewhere on the board
D7: IC1.2 (Din), IC16.9 (O0b); also elsewhere on the board
D.Out: IC16.1 (OEa), IC16.19 (OEb), IC33.15 (O0)
DA0: IC15.8 (DA0); also elsewhere on the board
DO0: IC8.14 (Dout), IC16.15 (I2b); also elsewhere on the board
DO1: IC7.14 (Dout), IC16.13 (I1b); also elsewhere on the board
DO2: IC6.14 (Dout), IC16.4 (I1a); also elsewhere on the board
DO3: IC5.14 (Dout), IC16.2 (I0a); also elsewhere on the board
DO4: IC4.14 (Dout), IC16.17 (I3b); also elsewhere on the board
DO5: IC3.14 (Dout), IC16.6 (I2a); also elsewhere on the board
DO6: IC2.14 (Dout), IC16.8 (I3a); also elsewhere on the board
DO7: IC1.14 (Dout), IC16.11 (I0b); also elsewhere on the board
E: IC15.13 (E), IC31.11; also elsewhere on the board
EXTMEN: IC33.6 (E3), R39.1; also elsewhere on the board
GND: C10.2, C11.2, C12.2, C13.2, C14.1, C15.1, C16.1, C17.1, C18.1, C19.1, C20.1, C21.1, C37.2, C40.1, C41.1, C50.2, C51.2, C52.2, C53.2, C54.2, C55.2, C56.2, C57.2, C58.2, C59.2, IC1.16 (VSS), IC2.16 (VSS), IC3.16 (VSS), IC4.16 (VSS), IC5.16 (VSS), IC6.16 (VSS), IC7.16 (VSS), IC8.16 (VSS), IC15.20 (GND), IC16.10 (GND), IC33.5 (E2), IC33.8 (GND), R66.1; also elsewhere on the board
unnamed: C40.2, IC15.5 (OSCIN), XL2.1
unnamed: C41.2, R37.2, XL2.2
unnamed: IC15.6 (OSCOUT), R37.1
unnamed: IC15.10 (~WE), R28.2
unnamed: IC15.11 (~CAS), R27.2
unnamed: IC15.12 (~RAS0), R26.2
unnamed: IC15.28 (Z0), R25.2
unnamed: IC15.29 (Z1), R24.2
unnamed: IC15.30 (Z2), R23.2
unnamed: IC15.31 (Z3), R22.2
unnamed: IC15.32 (Z4), R20.2
unnamed: IC15.33 (Z5), R19.2
unnamed: IC15.34 (Z6), R21.2
unnamed: IC31.4, JP1-2.3 (B)
unnamed: IC31.13, IC33.4 (E1)
unnamed: JP1-2.2 (C), R12.2
unnamed: JP7-8.3 (B), R12.1
P0: IC33.11 (O4); also elsewhere on the board
P1: IC33.10 (O5); also elsewhere on the board
P2: IC33.9 (O6); also elsewhere on the board
Q: IC15.14 (Q); also elsewhere on the board
R2: IC33.12 (O3); also elsewhere on the board
RAM VBB: C10.1, C50.1, C51.1, C52.1, C53.1, C54.1, C55.1, C56.1, C57.1, IC1.1 (VBB), IC2.1 (VBB), IC3.1 (VBB), IC4.1 (VBB), IC5.1 (VBB), IC6.1 (VBB), IC7.1 (VBB), IC8.1 (VBB), JP3-4.2 (C)
RAM VCC: C12.1, C58.1, IC1.9 (VCC), IC2.9 (VCC), IC3.9 (VCC), IC4.9 (VCC), IC5.9 (VCC), IC6.9 (VCC), IC7.9 (VCC), IC8.9 (VCC), JP7-8.2 (C)
RAM VDD: C11.1, C14.2, C15.2, C16.2, C17.2, C18.2, C19.2, C20.2, C21.2, IC1.8 (VDD), IC2.8 (VDD), IC3.8 (VDD), IC4.8 (VDD), IC5.8 (VDD), IC6.8 (VDD), IC7.8 (VDD), IC8.8 (VDD), JP5-6.2 (C)
R/~W: IC15.15 (R/~W); also elsewhere on the board
S0: IC15.27 (S0), IC33.1 (A0)
S1: IC15.26 (S1), IC33.2 (A1)
S2: IC15.25 (S2), IC31.12, IC33.3 (A2)
VCLK: IC15.7 (VCLK); also elsewhere on the board
Z0: IC1.5 (A0), IC2.5 (A0), IC3.5 (A0), IC4.5 (A0), IC5.5 (A0), IC6.5 (A0), IC7.5 (A0), IC8.5 (A0), R25.1
Z1: IC1.7 (A1), IC2.7 (A1), IC3.7 (A1), IC4.7 (A1), IC5.7 (A1), IC6.7 (A1), IC7.7 (A1), IC8.7 (A1), R24.1
Z2: IC1.6 (A2), IC2.6 (A2), IC3.6 (A2), IC4.6 (A2), IC5.6 (A2), IC6.6 (A2), IC7.6 (A2), IC8.6 (A2), R23.1
Z3: IC1.12 (A3), IC2.12 (A3), IC3.12 (A3), IC4.12 (A3), IC5.12 (A3), IC6.12 (A3), IC7.12 (A3), IC8.12 (A3), R22.1
Z4: IC1.11 (A4), IC2.11 (A4), IC3.11 (A4), IC4.11 (A4), IC5.11 (A4), IC6.11 (A4), IC7.11 (A4), IC8.11 (A4), R20.1
Z5: IC1.10 (A5), IC2.10 (A5), IC3.10 (A5), IC4.10 (A5), IC5.10 (A5), IC6.10 (A5), IC7.10 (A5), IC8.10 (A5), R19.1
Z6: IC1.13 (A6), IC2.13 (A6), IC3.13 (A6), IC4.13 (A6), IC5.13 (A6), IC6.13 (A6), IC7.13 (A6), IC8.13 (A6), R21.1
Z7: IC15.35 (Z7(~RAS1)), IC31.5, IC31.6, JP1-2.1 (A)
~CAS: IC1.15 (~CAS), IC2.15 (~CAS), IC3.15 (~CAS), IC4.15 (~CAS), IC5.15 (~CAS), IC6.15 (~CAS), IC7.15 (~CAS), IC8.15 (~CAS), R27.1
~E17: IC33.13 (O2); also elsewhere on the board
~E18: IC33.14 (O1); also elsewhere on the board
~NHS: IC15.9 (~HS); also elsewhere on the board
~RAS0: C59.1, IC1.4 (~RAS), IC2.4 (~RAS), IC3.4 (~RAS), IC4.4 (~RAS), IC5.4 (~RAS), IC6.4 (~RAS), IC7.4 (~RAS), IC8.4 (~RAS), R26.1, R66.2; also elsewhere on the board
~WE: IC1.3 (~WE), IC2.3 (~WE), IC3.3 (~WE), IC4.3 (~WE), IC5.3 (~WE), IC6.3 (~WE), IC7.3 (~WE), IC8.3 (~WE), R28.1

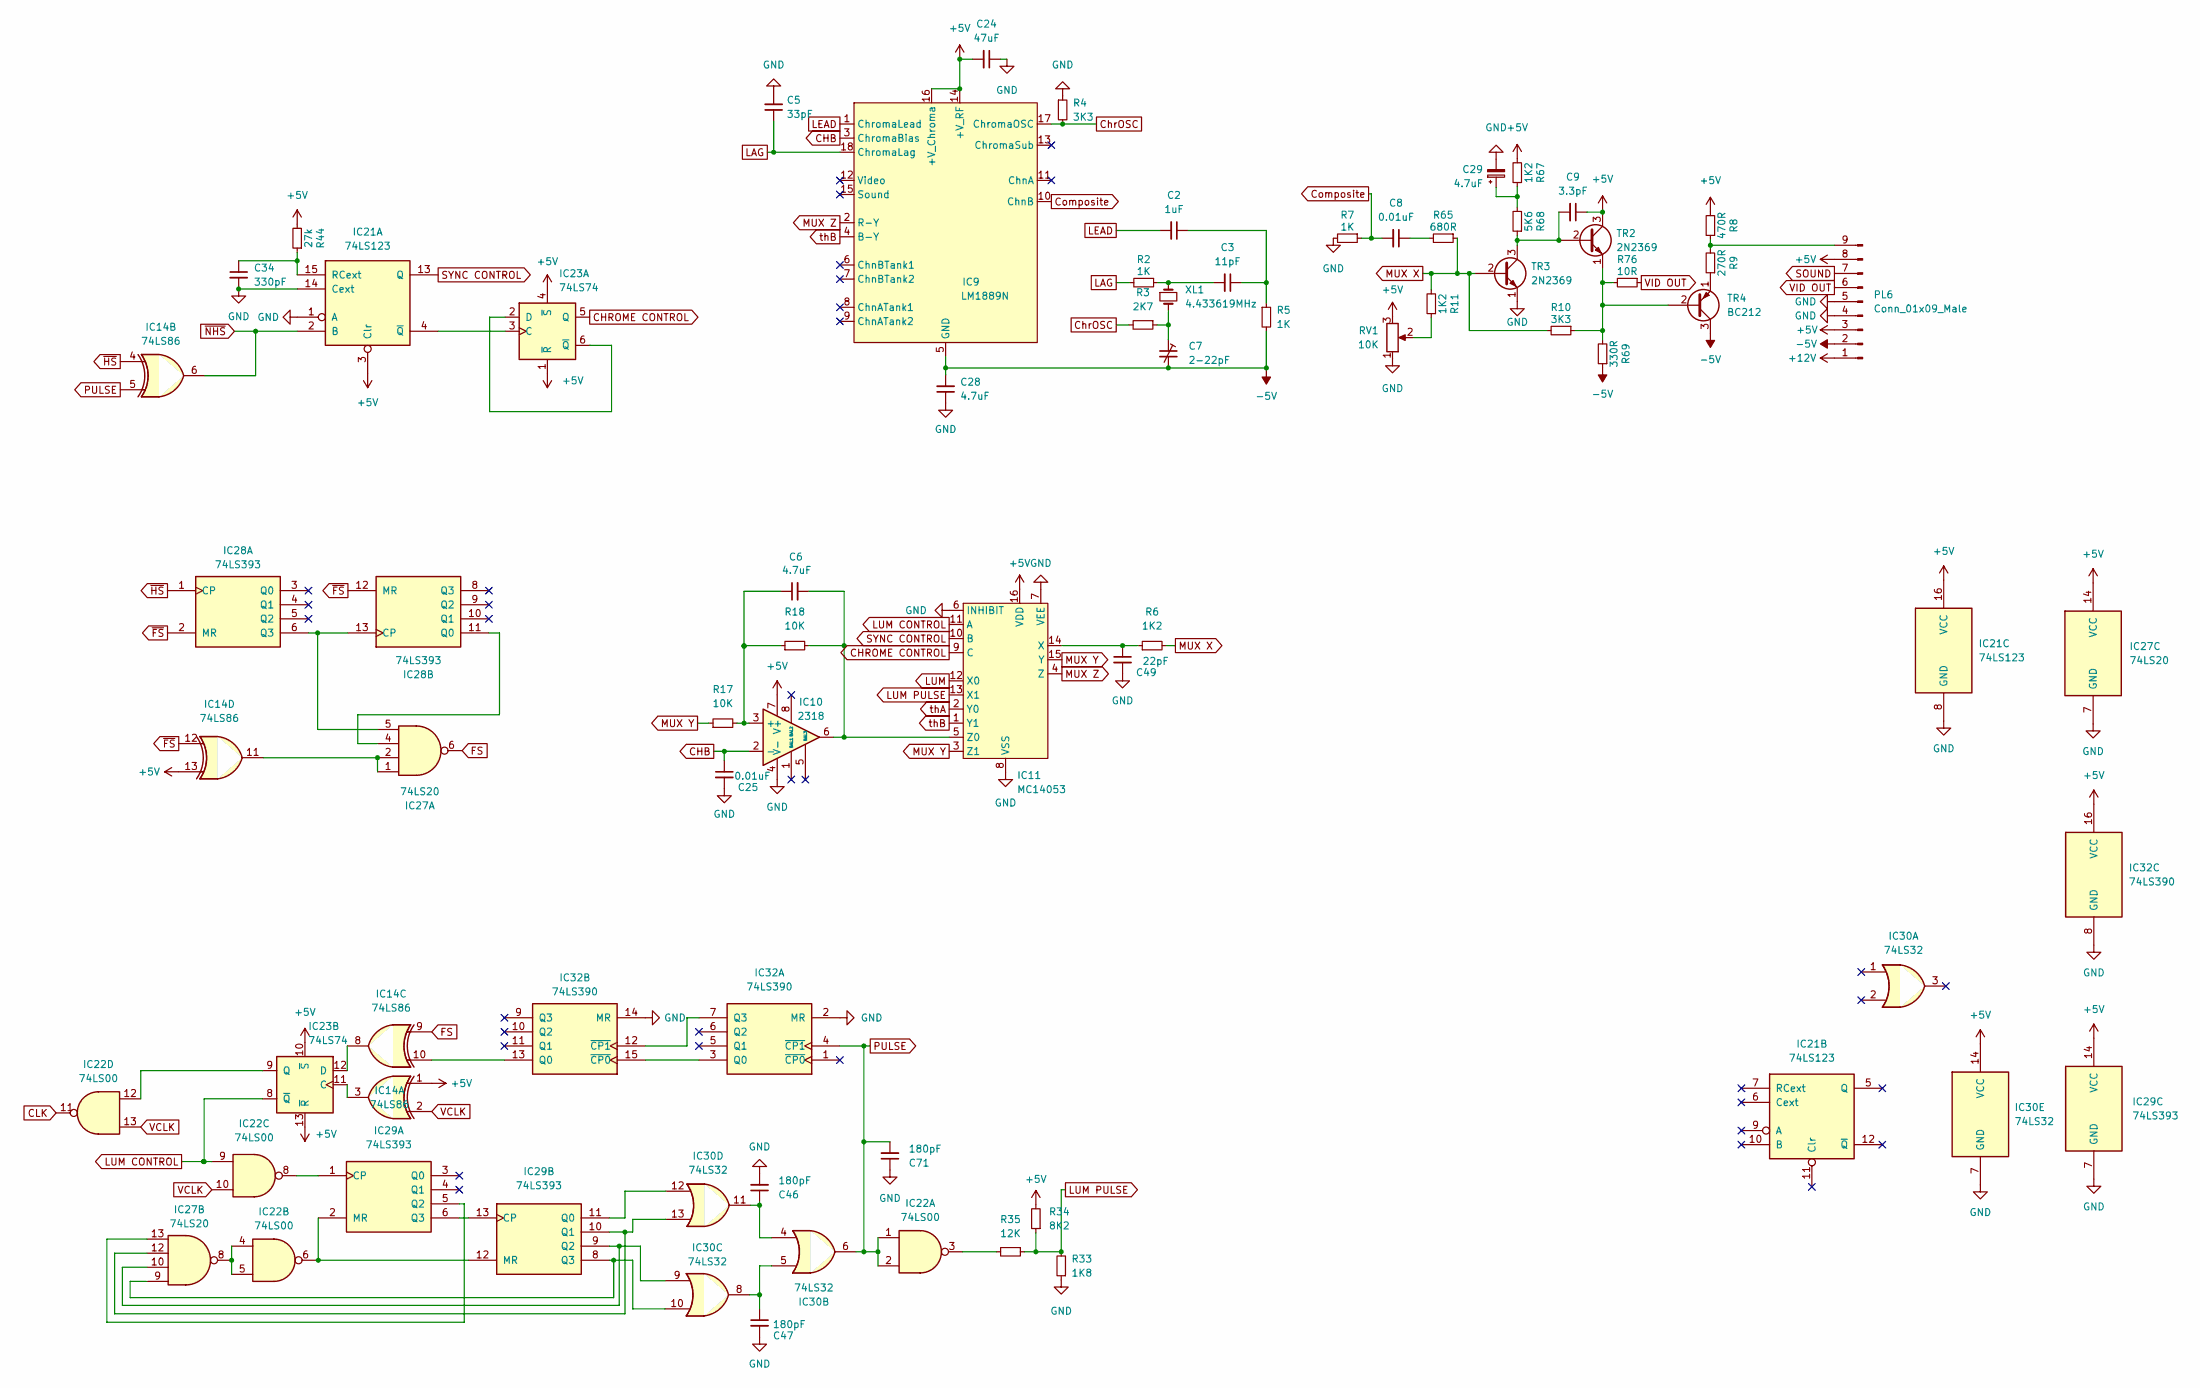
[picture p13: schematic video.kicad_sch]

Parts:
C2: 1uF; C_Disc_D3.0mm_W2.0mm_P2.50mm
C3: 11pF; C_Disc_D3.0mm_W2.0mm_P2.50mm
C5: 33pF; C_Disc_D3.0mm_W2.0mm_P2.50mm
C6, C28: 4.7uF; C_Disc_D3.0mm_W2.0mm_P2.50mm
C7: 2-22pF; Potentiometer_ACP_CA6-H2,5_Horizontal
C8, C25: 0.01uF; C_Disc_D3.0mm_W2.0mm_P2.50mm
C9: 3.3pF; C_Disc_D3.0mm_W2.0mm_P2.50mm
C24: 47uF; C_Disc_D3.0mm_W2.0mm_P2.50mm
C29: 4.7uF; CP_Radial_D5.0mm_P2.50mm
C34: 330pF; C_Disc_D3.0mm_W2.0mm_P2.50mm
C46, C47, C71: 180pF; C_Disc_D3.0mm_W2.0mm_P2.50mm
C49: 22pF; C_Disc_D3.0mm_W2.0mm_P2.50mm
IC9: LM1889N; DIP-18_W7.62mm
IC10: 2318; DIP-8_W7.62mm
IC11: MC14053; DIP-16_W7.62mm
IC14: 74LS86; DIP-14_W7.62mm
IC21: 74LS123; DIP-16_W7.62mm
IC22: 74LS00; DIP-14_W7.62mm
IC23: 74LS74; DIP-14_W7.62mm
IC27: 74LS20; DIP-14_W7.62mm
IC28, IC29: 74LS393; DIP-14_W7.62mm
IC30: 74LS32; DIP-14_W7.62mm
IC32: 74LS390; DIP-16_W7.62mm
PL6: Conn_01x09_Male; Molex_KK-396_A-41791-0009_1x09_P3.96mm_Vertical
R2, R5, R7: 1K; R_Axial_DIN0207_L6.3mm_D2.5mm_P10.16mm_Horizontal
R3: 2K7; R_Axial_DIN0207_L6.3mm_D2.5mm_P10.16mm_Horizontal
R4, R10: 3K3; R_Axial_DIN0207_L6.3mm_D2.5mm_P10.16mm_Horizontal
R6, R11, R67: 1K2; R_Axial_DIN0207_L6.3mm_D2.5mm_P10.16mm_Horizontal
R8: 470R; R_Axial_DIN0207_L6.3mm_D2.5mm_P10.16mm_Horizontal
R9: 270R; R_Axial_DIN0207_L6.3mm_D2.5mm_P10.16mm_Horizontal
R17, R18: 10K; R_Axial_DIN0207_L6.3mm_D2.5mm_P10.16mm_Horizontal
R33: 1K8; R_Axial_DIN0207_L6.3mm_D2.5mm_P10.16mm_Horizontal
R34: 8K2; R_Axial_DIN0207_L6.3mm_D2.5mm_P10.16mm_Horizontal
R35: 12K; R_Axial_DIN0207_L6.3mm_D2.5mm_P10.16mm_Horizontal
R44: 27k; R_Axial_DIN0207_L6.3mm_D2.5mm_P10.16mm_Horizontal
R65: 680R; R_Axial_DIN0207_L6.3mm_D2.5mm_P10.16mm_Horizontal
R68: 5K6; R_Axial_DIN0207_L6.3mm_D2.5mm_P10.16mm_Horizontal
R69: 330R; R_Axial_DIN0207_L6.3mm_D2.5mm_P10.16mm_Horizontal
R76: 10R; R_Axial_DIN0207_L6.3mm_D2.5mm_P10.16mm_Horizontal
RV1: 10K; Potentiometer_ACP_CA9-H5_Horizontal
TR2, TR3: 2N2369; TO-92_Inline
TR4: BC212; TO-92_Inline
XL1: 4.433619MHz; Crystal_HC18-U_Horizontal

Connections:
+5V: C9.1, C24.2, IC9.14 (+V_RF), IC9.16 (+V_Chroma), IC10.7 (V+), IC11.16 (VDD), IC14.1, IC14.13, IC21.3 (Clr), IC21.16 (VCC), IC23.1 (~R), IC23.4 (~S), IC23.10 (~S), IC23.13 (~R), IC27.14 (VCC), IC29.14 (VCC), IC30.14 (VCC), IC32.16 (VCC), PL6.3, PL6.8, R8.2, R34.2, R44.2, R67.2, RV1.3, TR2.3 (C); also elsewhere on the board
+12V: PL6.1; also elsewhere on the board
-5V: C7.2, C28.2, IC9.5 (GND), PL6.2, R5.2, R69.1, TR4.3 (C); also elsewhere on the board
CHB: C25.1, IC9.3 (ChromaBias), IC10.2 (-); also elsewhere on the board
CHROME CONTROL: IC11.9 (C), IC23.5 (Q)
CLK: IC22.11; also elsewhere on the board
ChrOSC: IC9.17 (ChromaOSC), R3.2, R4.2
Composite: C8.2, IC9.10 (ChnB), R7.1
FS: IC14.9, IC27.6
GND: C5.2, C24.1, C25.2, C28.1, C29.2, C34.2, C46.2, C47.2, C49.2, C71.1, IC10.4 (V-), IC11.6 (INHIBIT), IC11.7 (VEE), IC11.8 (VSS), IC21.1 (A), IC21.8 (GND), IC21.14 (Cext), IC27.7 (GND), IC29.7 (GND), IC30.7 (GND), IC32.2 (MR), IC32.8 (GND), IC32.14 (MR), PL6.4, PL6.5, R4.1, R7.2, R33.1, RV1.1, TR3.1 (E); also elsewhere on the board
LAG: C5.1, IC9.18 (ChromaLag), R2.2
LEAD: C2.2, IC9.1 (ChromaLead)
LUM: IC11.12 (X0); also elsewhere on the board
LUM CONTROL: IC11.11 (A)
LUM PULSE: IC11.13 (X1), R33.2, R34.1, R35.1
MUX X: R6.2, R10.2, R11.2, R65.1, TR3.2 (B)
MUX Y: IC11.3 (Z1), IC11.15 (Y), R17.1
MUX Z: IC9.2 (R-Y), IC11.4 (Z)
unnamed: C2.1, C3.1, R5.1
unnamed: C3.2, R2.1, XL1.1
unnamed: C6.1, IC10.3 (+), R17.2, R18.1
unnamed: C6.2, IC10.6, IC11.5 (Z0), R18.2
unnamed: C7.1, R3.1, XL1.2
unnamed: C8.1, R65.2
unnamed: C9.2, R68.1, TR2.2 (B), TR3.3 (C)
unnamed: C29.1, R67.1, R68.2
unnamed: C34.1, IC21.15 (RCext), R44.1
unnamed: C46.1, IC30.4, IC30.11
unnamed: C47.1, IC30.5, IC30.8
unnamed: C49.1, IC11.14 (X), R6.1
unnamed: IC14.3, IC23.11 (C)
unnamed: IC14.8, IC23.12 (D)
unnamed: IC14.10, IC32.13 (Q0)
unnamed: IC14.11, IC27.1, IC27.2
unnamed: IC21.4 (~Q), IC23.3 (C)
unnamed: IC22.3, R35.2
unnamed: IC22.4, IC22.5, IC27.8
unnamed: IC22.6, IC29.2 (MR), IC29.12 (MR)
unnamed: IC22.8, IC29.1 (CP)
unnamed: IC22.9, IC23.8 (~Q)
unnamed: IC22.12, IC23.9 (Q)
unnamed: IC23.2 (D), IC23.6 (~Q)
unnamed: IC27.4, IC28.11 (Q0)
unnamed: IC27.5, IC28.6 (Q3), IC28.13 (CP)
unnamed: IC27.9, IC29.8 (Q3), IC30.10
unnamed: IC27.10, IC29.9 (Q2), IC30.9
unnamed: IC27.12, IC29.10 (Q1), IC30.13
unnamed: IC27.13, IC29.5 (Q2)
unnamed: IC29.11 (Q0), IC30.12
unnamed: IC29.6 (Q3), IC29.13 (CP)
unnamed: IC32.7 (Q3), IC32.12 (~CP1)
unnamed: IC32.3 (Q0), IC32.15 (~CP0)
unnamed: PL6.9, R8.1, R9.2
unnamed: R9.1, TR4.1 (E)
unnamed: R10.1, R69.2, R76.2, TR2.1 (E), TR4.2 (B)
unnamed: R11.1, RV1.2
PULSE: C71.2, IC14.5, IC22.1, IC22.2, IC30.6, IC32.4 (~CP1)
SOUND: PL6.7; also elsewhere on the board
SYNC CONTROL: IC11.10 (B), IC21.13 (Q)
VCLK: IC14.2, IC22.10, IC22.13; also elsewhere on the board
VID OUT: PL6.6, R76.1
thA: IC11.2 (Y0); also elsewhere on the board
thB: IC9.4 (B-Y), IC11.1 (Y1); also elsewhere on the board
~FS: IC14.12, IC28.2 (MR), IC28.12 (MR); also elsewhere on the board
~HS: IC14.4, IC28.1 (CP); also elsewhere on the board
~NHS: IC14.6, IC21.2 (B); also elsewhere on the board

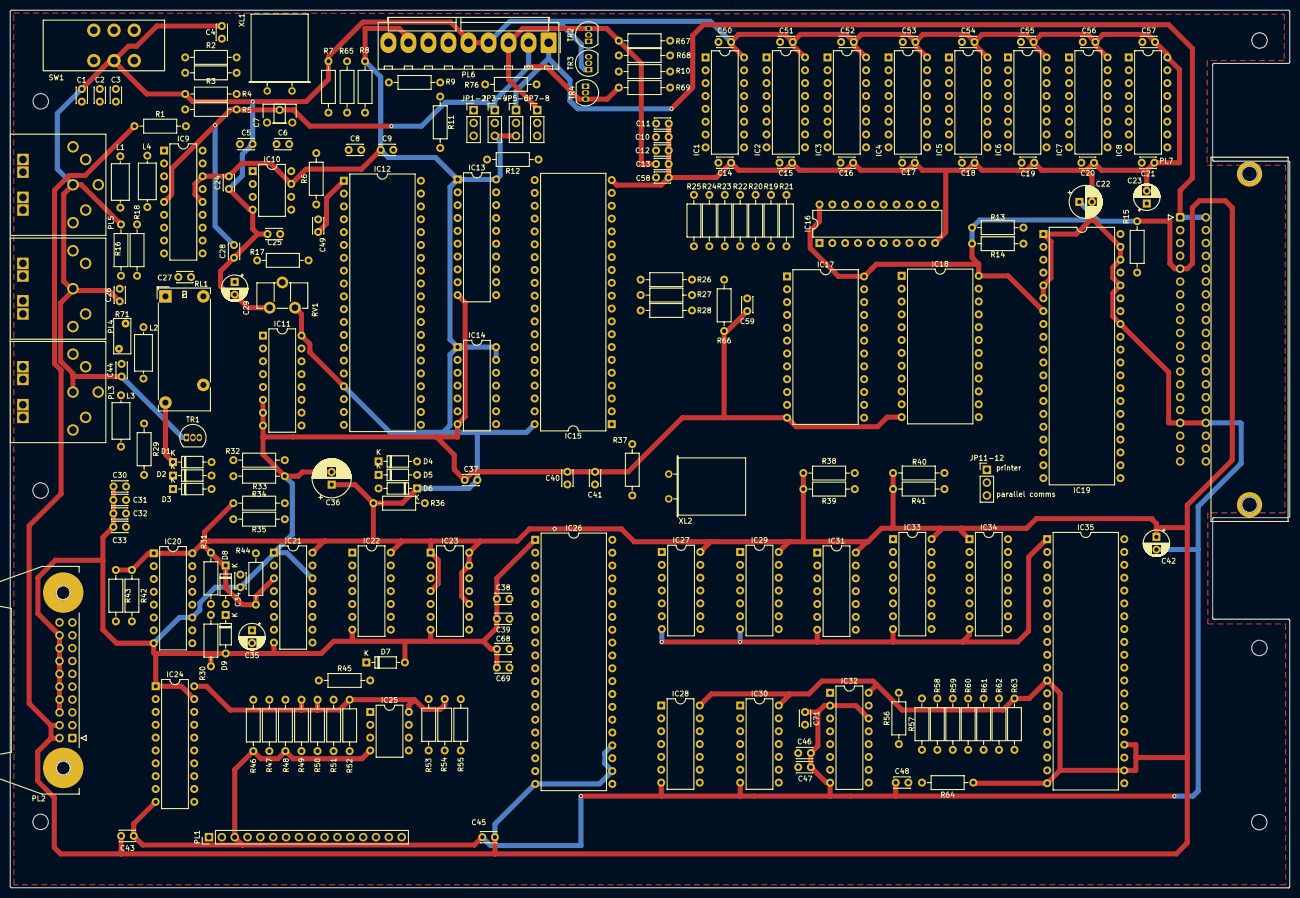
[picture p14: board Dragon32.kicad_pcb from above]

Board: 2 copper layers, 253.0 x 173.5 mm, 202 parts (0 on the bottom side), 234 nets.

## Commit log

2022-09-25 fix board dimensions
    [Dragon32.kicad_pcb, Dragon32.kicad_sch, pia1.kicad_sch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]
2022-09-25 add drill holes
    [Dragon32.kicad_pcb]
2022-09-25 resolve conflicts
    [Dragon32.dsn]
2022-09-25 update drawings
    [Dragon32.kicad_sch, mpu.kicad_sch, pia1.kicad_sch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]
2022-09-26 add 64k switch
    [Dragon32.kicad_sch, pia1.kicad_sch, pia2.kicad_sch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]
2022-09-26 tidy up pcb
2022-09-26 update interactive bom
2022-09-26 update simple bom
    [Dragon32.csv]
2022-09-26 add jumper 5 (position 9 and 10)
    [Dragon32.csv, Dragon32.kicad_sch, pia2.kicad_sch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]
2022-09-26 update notes
    [Dragon32.kicad_sch, mpu.kicad_sch, pia1.kicad_sch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]
2022-09-30 relocate dram and buffer to match original
    [Dragon32.csv, Dragon32.dsn, Dragon32.kicad_sch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]
2022-10-11 prepare board for drill hole fix
2022-10-12 revise edge connector
    [Dragon32.kicad_sch, pia1.kicad_sch, pia2.kicad_sch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]
2022-10-12 validate component values
    [Dragon32.kicad_sch, mpu.kicad_sch, pia1.kicad_sch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]
2022-10-12 resitor values pt1
    [Dragon32.kicad_sch, video.kicad_sch]
2022-10-13 complete component revision
    [Dragon32.kicad_sch, pia2.kicad_sch, video.kicad_sch]
2022-10-13 cross-reference items to suppliers
    [Dragon32.kicad_sch, pia1.kicad_sch, pia2.kicad_sch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]
2022-10-14 update part numbers
    [Dragon32.kicad_sch, mpu.kicad_sch, pia1.kicad_sch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]
2022-10-14 update bom
    [Dragon32.csv]
2022-10-14 provide renders of the board
2022-10-15 resolve part numbers
    [Dragon32.csv, Dragon32.kicad_sch, mpu.kicad_sch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]
2022-10-15 beautify the board
    [Dragon32.kicad_sch, mpu.kicad_sch, pia1.kicad_sch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]
2022-10-15 fix broken PIA2 to multiplexer line
    [pia1.kicad_sch]
2022-10-15 label pins
    [sam.kicad_sch]
2022-10-16 fix video circuit gnd
    [Dragon32.kicad_sch, vdg.kicad_sch, video.kicad_sch]
2022-10-16 redraw video schematic for clarity
    [Dragon32.kicad_sch, video.kicad_sch]
2022-10-16 fix link IC25 to IC26
    [pia1.kicad_sch]
2022-10-17 fix edge connector and op-amp
    [Dragon32.kicad_sch, pia1.kicad_sch, pia2.kicad_sch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]
2022-10-18 refresh pcb
    [Dragon32.kicad_sch, mpu.kicad_sch, rom.kicad_sch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]
2022-10-19 fix relay footprint
    [Dragon32.kicad_sch, mpu.kicad_sch, pia1.kicad_sch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]
2022-10-21 update pcb
    [Dragon32.kicad_sch]
2022-10-28 fix typo on 6833 silkscreen
2022-10-30 respace traces
    [Dragon32.kicad_sch, pia1.kicad_sch, pia2.kicad_sch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]
2022-10-31 revise power connector labels
2022-11-01 improve trace separation
    [Dragon32.kicad_sch, pia1.kicad_sch, pia2.kicad_sch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]
2022-11-01 add bypass for secondary video amp
    [Dragon32.kicad_sch, video.kicad_sch]
2022-11-07 improve trace clearance
2022-11-07 rewire 5v lines
    [Dragon32.kicad_sch, video.kicad_sch]
2022-11-08 update silkscreen
    [Dragon32.csv]
2022-11-08 improve layout
    [Dragon32.kicad_sch, mpu.kicad_sch, pia1.kicad_sch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]
2022-12-08 improve 12v routes
2022-12-20 verify video logic
    [Dragon32.dsn, Dragon32.kicad_sch, pia1.kicad_sch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]
2022-12-21 fix line pulse counter ic32
    [Dragon32.kicad_sch, pia1.kicad_sch, pia2.kicad_sch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]
2022-12-27 reroute video circuit
    [Dragon32.kicad_sch, pia1.kicad_sch, pia2.kicad_sch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]
2023-01-03 reroute power
    [Dragon32.kicad_sch, mpu.kicad_sch, pia1.kicad_sch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]
2023-01-06 improve ram zone groundplane
2023-01-06 rework RV3
    [Dragon32.kicad_sch, pia2.kicad_sch]
2023-01-07 update capacitor values for joystick button input
    [Dragon32.kicad_sch, pia1.kicad_sch]
2023-01-08 add trace labels for joysticks
    [Dragon32.kicad_sch, pia1.kicad_sch]
2023-01-08 fix +v rail on IC25 comparator
    [Dragon32.kicad_sch]
2023-01-08 fix dac
    [pia2.kicad_sch]
2023-01-09 review line counter
    [Dragon32.kicad_sch, pia1.kicad_sch, pia2.kicad_sch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]
2023-01-12 improve annotation of dac
    [Dragon32.kicad_sch, pia2.kicad_sch]
2023-01-12 provide on board annotation of dac
2023-01-13 rewire relay position
    [pia2.kicad_sch]
2023-01-13 refine 12v trace
2023-01-14 revise component values
    [Dragon32.kicad_sch, pia1.kicad_sch, pia2.kicad_sch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]
2023-01-14 Revert "improve trace clearance"
    This reverts commit 3cf644d67ec5c70c51931af734b43aed31f61206.
2023-01-27 fix voltage wiring
    [Dragon32.kicad_sch, mpu.kicad_sch, pia1.kicad_sch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]
2023-02-10 fix c7 footprint
    [Dragon32.kicad_sch, pia1.kicad_sch, pia2.kicad_sch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]
2023-02-14 upgrade to kicad 7
    [Dragon32.kicad_sch, mpu.kicad_sch, pia1.kicad_sch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]
2023-02-18 fix chroma output from IC9
    [video.kicad_sch]
2023-02-18 fix inputs to video amp
    [video.kicad_sch]
2023-02-22 update page settings
    [Dragon32.kicad_sch, mpu.kicad_sch, pia1.kicad_sch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]
2023-02-22 fix video amp cap value
    [video.kicad_sch]
2023-02-22 remove autoroute files
    [Dragon32.dsn]
2023-05-09 revise video circuit
    [sam.kicad_sch, video.kicad_sch]
2023-05-10 Update component values
    [video.kicad_sch]
2023-05-10 Refine schematic detail and pcb traces
    [sam.kicad_sch, video.kicad_sch]
2023-05-10 fix vs code butchering of schematics
    [video.kicad_sch]
2023-05-14 repair damaged pcb definition
2023-05-20 Update README.md
    Report video circuit working
2023-05-20 annotate video schematic
    [video.kicad_sch]
2023-05-20 update for release 2.0
    [Dragon32.kicad_sch, mpu.kicad_sch, pia1.kicad_sch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]
2023-06-03 add ntsc config
    [sam.kicad_sch]
2023-06-03 increase revision
    [Dragon32.kicad_sch, mpu.kicad_sch, pia1.kicad_sch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]
2023-06-03 add video pickup
    [video.kicad_sch]
2023-06-10 fix diff amp wiring
    [video.kicad_sch]
2023-06-13 refill ground
2023-06-24 optimise traces
2023-08-11 revise bom
    [Dragon32.csv, pia2.kicad_sch]
2025-08-15 update board for revision 2.2
    [Dragon32.kicad_sch, mpu.kicad_sch, pia1.kicad_sch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]
2025-08-28 update bom references
    [Dragon32.csv, Dragon32.kicad_sch, mpu.kicad_sch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]
2025-11-11 fix parallel strobe inverter bypass
    [Dragon32.kicad_sch, mpu.kicad_sch, pia1.kicad_sch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]
